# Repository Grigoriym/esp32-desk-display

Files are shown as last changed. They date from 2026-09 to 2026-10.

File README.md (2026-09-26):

# ESP32 Desk Display

A small always-on desk companion: an ESP32 drives a 0.96" OLED that shows
the time, the weather outside and inside, air quality and pollen, DWD
weather warnings, public holidays and the next U-Bahn departures. A rotary
knob switches between screens. Readings are also uploaded to a self-hosted
InfluxDB + Grafana dashboard, and a phone on the same WiFi can see them and
switch screens at `http://desk.local`.

Written in C on ESP-IDF, with a small hand-rolled SSD1306 driver and no
graphics library. All data sources are free and need no API key.

## Screens

Every screen has the time (`HH:MM`) flush left and the date (`DD/MM/YYYY`)
flush right on the top row. Turn the knob to go to the next or previous
screen (it wraps around). Press it to turn the panel off, and again to turn
it back on. Turning the knob while the panel is off also wakes it.

| Screen | Shows |
|---|---|
| **HOME** | DWD weather warning if one is out, otherwise the next public holiday; weather icon + outdoor temperature; indoor `IN 25C 43H`; rain hint (`RAIN 14:00`, `RAIN TILL 16:00`, `NO RAIN 12H`) |
| **OUTDOOR** | Sunrise/sunset, wind speed, today's max UV index |
| **AIR** | European AQI with its label, the two strongest pollen types and their levels |
| **INDOOR** | Temperature, humidity, pressure in hPa (BME280) |
| **BVG** | Next U-Bahn departures from one stop in one direction, with a `LEAVE IN N` / `GO NOW` / `HURRY` hint. One click counter-clockwise from HOME |

The font only has A-Z, 0-9, `:`, `-` and `/`, so `H` stands in for `%`.

At boot a status screen shows each subsystem coming up, with `--` changing
to `OK` or `NO`:

```
         HELLO

OLED    OK   PWR     OK
RTC     OK   BME     OK

WIFI    OK   NTP     OK
WEATHER OK
```

`PWR NO` means the last reset was a brownout (weak USB port or cable).

## Data sources

| Data | Source | Refresh |
|---|---|---|
| Time | NTP, kept through power loss by the DS3231 RTC (stores UTC) | RTC at boot, NTP after WiFi is up |
| Weather, sun, wind, UV, rain | [Open-Meteo](https://open-meteo.com/) forecast API | 15 min |
| Air quality, pollen | Open-Meteo air-quality API | 15 min |
| Weather warnings | DWD via [Bright Sky](https://brightsky.dev/) `/alerts` | 15 min |
| Public holidays | [Nager.Date](https://date.nager.at/) (Berlin + nationwide) | once a year |
| Departures | [`v6.bvg.transport.rest`](https://v6.bvg.transport.rest/) (community-run, has outages) | 60 s, only while the BVG screen is showing |
| Indoor | BME280 | 10 s |

A failed weather fetch is retried after 30 s, then at growing intervals up
to the normal 15 minutes.

## Resilience

- No RTC: the clock waits for NTP. No NTP: the RTC time is used.
- No WiFi within 15 s: boot shows `WIFI NO` and goes to the main screens on
  RTC time. WiFi keeps retrying in the background, and NTP and the weather
  follow once it connects.
- The BVG fetch and the dashboard upload run in their own tasks, so a slow
  or down server never freezes the clock or the knob.
- Summer/winter time switches automatically (POSIX TZ rule).

## Hardware

| Part | Notes |
|---|---|
| ESP32 DevKit (WROOM-32, 30-pin, 4 MB flash) | |
| 0.96" 128x64 I2C OLED, SSD1306/SSD1315 | I2C `0x3C` |
| DS3231 RTC module with coin cell | I2C `0x68`. Optional but recommended |
| BME280 | I2C `0x76`. Optional (indoor readings) |
| KY-040 rotary encoder | GPIO25/26/27. Optional (screen switching) |

All I2C modules share one bus (SDA GPIO21, SCL GPIO22), each wired
**directly to the ESP32, in parallel**, and powered from **3V3, never
5V**. Full pin table: [`docs/WIRING.md`](docs/WIRING.md).

## Build and flash

Requires [ESP-IDF](https://docs.espressif.com/projects/esp-idf/) (developed
on master, v6.x).

```sh
cp main/wifi_secrets.h.example    main/wifi_secrets.h     # SSID/password
cp main/bvg_secrets.h.example     main/bvg_secrets.h      # stop + direction IDs
cp main/metrics_secrets.h.example main/metrics_secrets.h  # dashboard host/token, empty = off
. ~/esp/esp-idf/export.sh
idf.py -p /dev/ttyUSB0 build flash monitor
```

The `*_secrets.h` files are gitignored, so credentials never get committed.
cJSON is pulled in automatically by the component manager.

## Dashboard

`server/` holds an InfluxDB 2 + Grafana setup in Docker Compose. The display
POSTs indoor, outdoor, air-quality and device values (heap, WiFi signal,
uptime) every minute. Run it on an always-on machine on the display's LAN:
see [`server/README.md`](server/README.md) and
[`server/INSTALL.md`](server/INSTALL.md).

## Phone access and API

The display serves a small page at **`http://desk.local`** (mDNS; the IP
from the boot log works too) with everything the screens show, refreshed
every 5 s, plus buttons for the screens and the panel. Home WiFi only, and
**no authentication**: anyone on the LAN can read it and switch screens.

| Request | Does |
|---|---|
| `GET /api/status` | JSON: `time`, `date` (`YYYY-MM-DD`), `screen`, `panel_on`, and `outdoor`, `indoor`, `air`, `warning`, `next_holiday`, `bvg`. A section is `null` until its first fetch or read succeeds (`--` on the panel); `warning` is `{"count": 0}` when there is none |
| `POST /api/screen?go=next\|prev\|home\|outdoor\|air\|indoor\|bvg` | Switch screens, like turning the knob. A screen by name also turns the panel on; `next`/`prev` while it's off only wake it, as the knob does |
| `POST /api/panel?set=on\|off\|toggle` | Panel on/off, like pressing the knob |

Commands answer `{"ok":true}` (`400` for a bad value) and apply within a
few hundred ms, or once a running fetch finishes. While `/api/status` is
being read (the last 2 minutes), departures are fetched even if the BVG
screen isn't up. The server also announces itself as `_http._tcp` for
discovery (Android NSD). Full contract (every field, discovery, errors,
polling): [`docs/API.md`](docs/API.md).

## Configuration

Settings are hardcoded constants. Change them and reflash:

| What | Where |
|---|---|
| Location (default: central Berlin) | `WEATHER_URL`, `AIR_URL`, `ALERTS_URL` in `main/weather.c` |
| Holiday region (default: `DE-BE`) | `HOLIDAYS_REGION` in `main/holidays.c` |
| Timezone (default: Berlin, automatic DST) | `LOCAL_TZ` in `main/clock.c` |
| Refresh intervals, WiFi timeout | `*_SECONDS` in `main/main.c` |
| BVG stop, direction, walking time | `main/bvg_secrets.h` |
| Display orientation | `0xA0`/`0xC0` in the init sequence in `main/display.c` (this build's panel is mounted upside-down; use `0xA1`/`0xC8` for the default orientation) |

## Development

Run these before pushing; CI (`.github/workflows/ci.yml`) runs the same on
every push:

| Script | Does |
|---|---|
| `tools/test.sh` | Host unit tests (Unity, ASan/UBSan) for the pure logic: parsers, screen layouts, font and icon bitmaps, time math, encoder decoding |
| `tools/format.sh` | clang-format (`--check` only reports) |
| `tools/lint.sh` | clang-tidy, checks in `.clang-tidy` |
| `tools/size_check.sh` | Fails if the app partition has under 15% free |
| `tools/serial_log.py [seconds] [regex]` | Resets the board and captures/greps the serial log |

clang-format and clang-tidy come from ESP-IDF's optional `esp-clang` tool.
New files are only checked once they're `git add`-ed.

## Project layout

```
main/
  main.c            boot sequence, status screen, main loop, knob handling
  screens.c         what each screen shows (pure, host-tested)
  display.c         SSD1306 driver; font.c: 5x7 font and icons
  clock.c           NTP sync, DS3231; clock_time.c: time math
  wifi.c            WiFi station
  http.c            shared HTTPS GET
  weather.c         weather, air quality and warnings fetch
  weather_parse.c   \
  air_parse.c        | JSON parsing (pure, host-tested)
  alerts_parse.c    /
  holidays.c        public holidays; holidays_parse.c
  bvg.c             departures, own task; bvg_parse.c
  bme280.c          indoor sensor driver
  encoder.c         KY-040 ISR + button task; encoder_decode.c
  metrics.c         dashboard upload, own task; metrics_format.c
  health.c          periodic heap/stack report in the log
  web.c             phone page + JSON API, mDNS; web_api.c (pure,
                    host-tested), page in web_index.html
test/               host unit tests + fixtures
tools/              test, format, lint, size and serial scripts
server/             InfluxDB + Grafana (Docker Compose)
docs/WIRING.md      pin table
```

Hardware bring-up tests (I2C scan, OLED pattern, BME280 chip ID, encoder)
live in a separate sibling project, `esp32-hw-checks`.

## License

[Apache License 2.0](LICENSE)

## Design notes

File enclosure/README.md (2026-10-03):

# Enclosure (ROADMAP task 15)

OpenSCAD model of the case, written from `MEASUREMENTS.md`. Open
`enclosure.scad` in OpenSCAD for the assembled view (modules shown as
coloured stand-in blocks). `-D cut=40` cuts the printed parts away left of
x = 40 to show the inside.

Part dimensions and how each part can be held: its Homebox entry
(`python3 ../../grappim-watcher/docs/esp32/inventory/parts.py show <part>`).
General modelling, clash-check and printability lessons:
`../../grappim-watcher/docs/esp32/ENCLOSURE_PLAYBOOK.md`. This file is this case only.

```
enclosure/export.sh   # clash check, then stl/enclosure/*.stl (gitignored) + renders/enclosure-*.png
```

The clash check fails if any printed part overlaps a module stand-in.

To look inside: **Window → Customizer**, untick `show_shell` (also
`show_base`, `show_hood`, `show_clamps`, `show_labels`), or set `cut`.
Stand-in colours: OLED steel blue, ESP32 black (antenna end orange),
carrier green, DS3231 navy, KY-040 red with a grey cap, sensors purple;
`show_labels` puts their names over them.

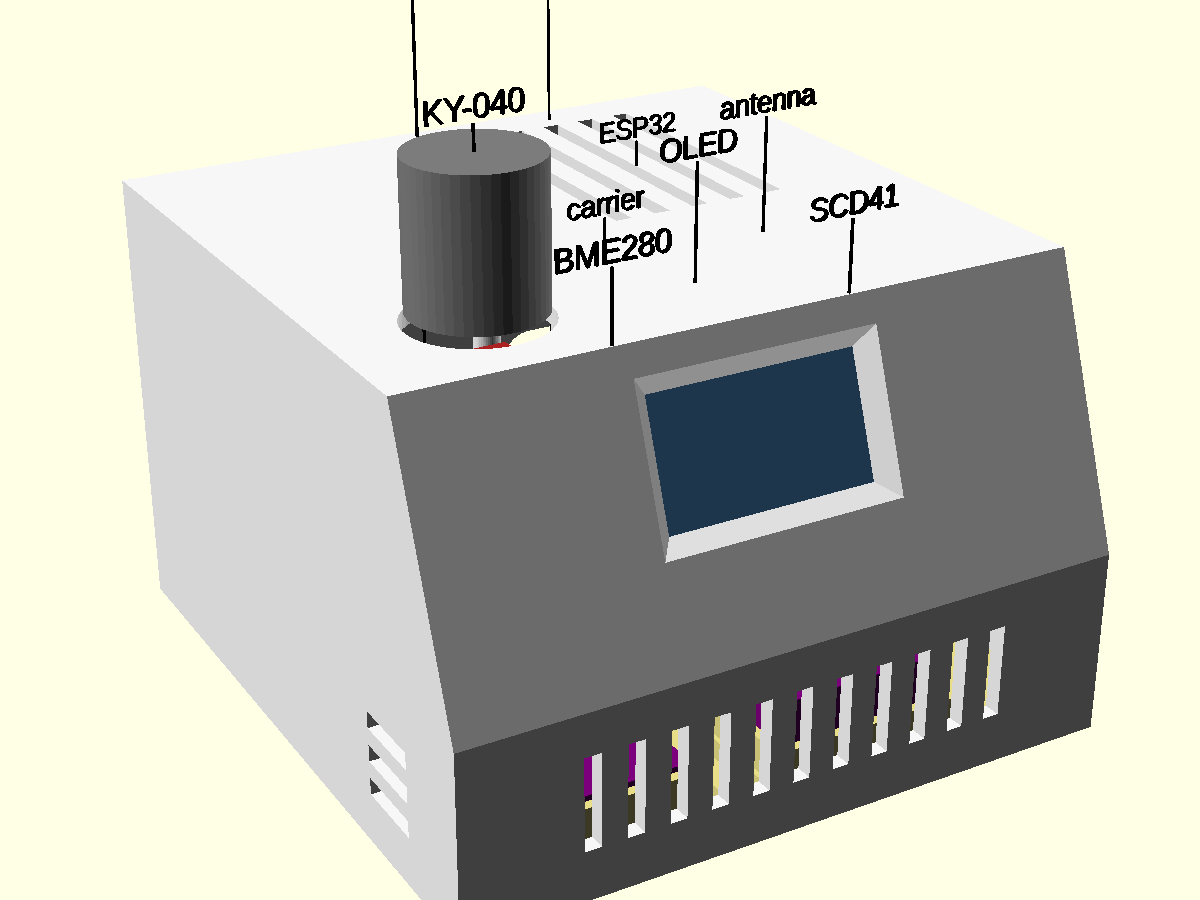
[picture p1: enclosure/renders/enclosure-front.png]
front
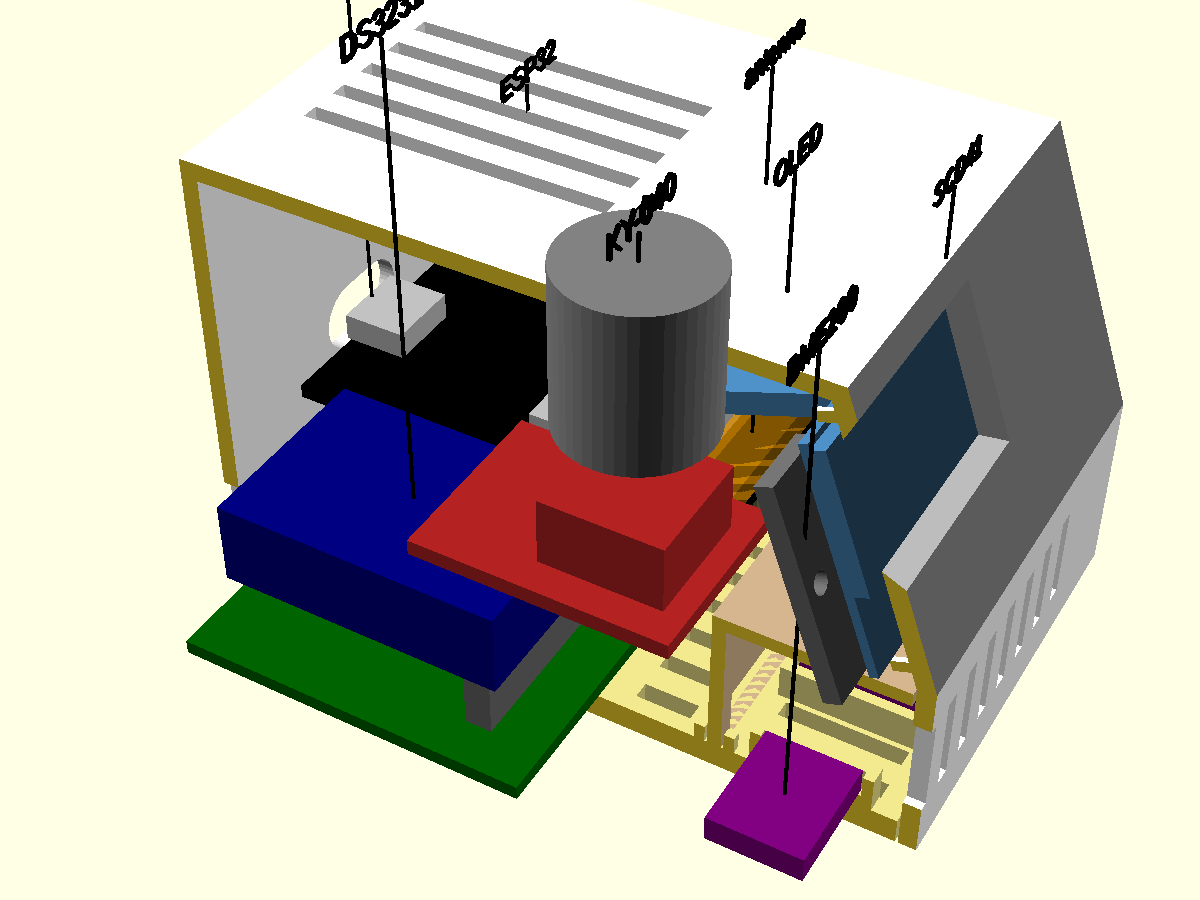
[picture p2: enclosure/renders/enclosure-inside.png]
inside
 

## v2: the carrier is the 4 x 6 cm board (`enclosure_v2.scad`)

The mock-up (2026-09-28) showed v1's carrier can't work: the 4 x 6 cm
perfboard has 14 holes across its 4 cm side, and an ESP32 pin row is 15, so
the ESP32 only fits along the 6 cm side. `enclosure.scad` (v1) is kept;
`enclosure_v2.scad` has two layouts, `carrier` in the Customizer:

| | `cut` | `whole` (**picked 2026-10-03**, the default) |
|---|---|---|
| board | turned front-to-back, cut to 40 x 44 (keep 17 hole rows) | uncut 60 x 40 |
| ESP32 | front-to-back | left-to-right |
| USB-C | out the back | out the right side |
| antenna | hangs off the board's front edge | over the board (and under the knob) |
| DS3231 | own holder on the floor, left, JST cable | own holder on the floor under the carrier (tall 16 mm standoffs), JST cable |
| case size | same 80 x 84 x 54 | same |

```
enclosure/export.sh enclosure_v2.scad carrier=cut        # or carrier=whole
enclosure/cardboard.py 2 enclosure_v2.scad carrier=cut   # -> cardboard-enclosure_v2-cut.pdf
```

**JST-XH sockets** are modelled on the board's hole grid (white, with the
mated plug + cable bend as a see-through gold block, labelled on top); the
clash check covers them against the ESP32, its headers, the DS3231 and the
case, and the model errors if one hangs off the board:

- `whole`: all five fit. BME280, SCD41, OLED along the front edge (row 0,
  under nothing; the plugs clear the ESP32's edge by only ~0.5 mm in plan),
  RTC and KNOB at the left end (col 0), next to the ESP32's antenna end.
- `cut`: only three fit (KNOB, OLED, SCD41, in the one free column left of
  the ESP32). **No room for BME280 and RTC**: the ESP32 covers the rest of
  the board, and a plug is too tall to go under it.

The hole grid is ASSUMED centred on the board. The DS3231's pins (both
ends) are modelled with the cable soldered on, not a Dupont plug.

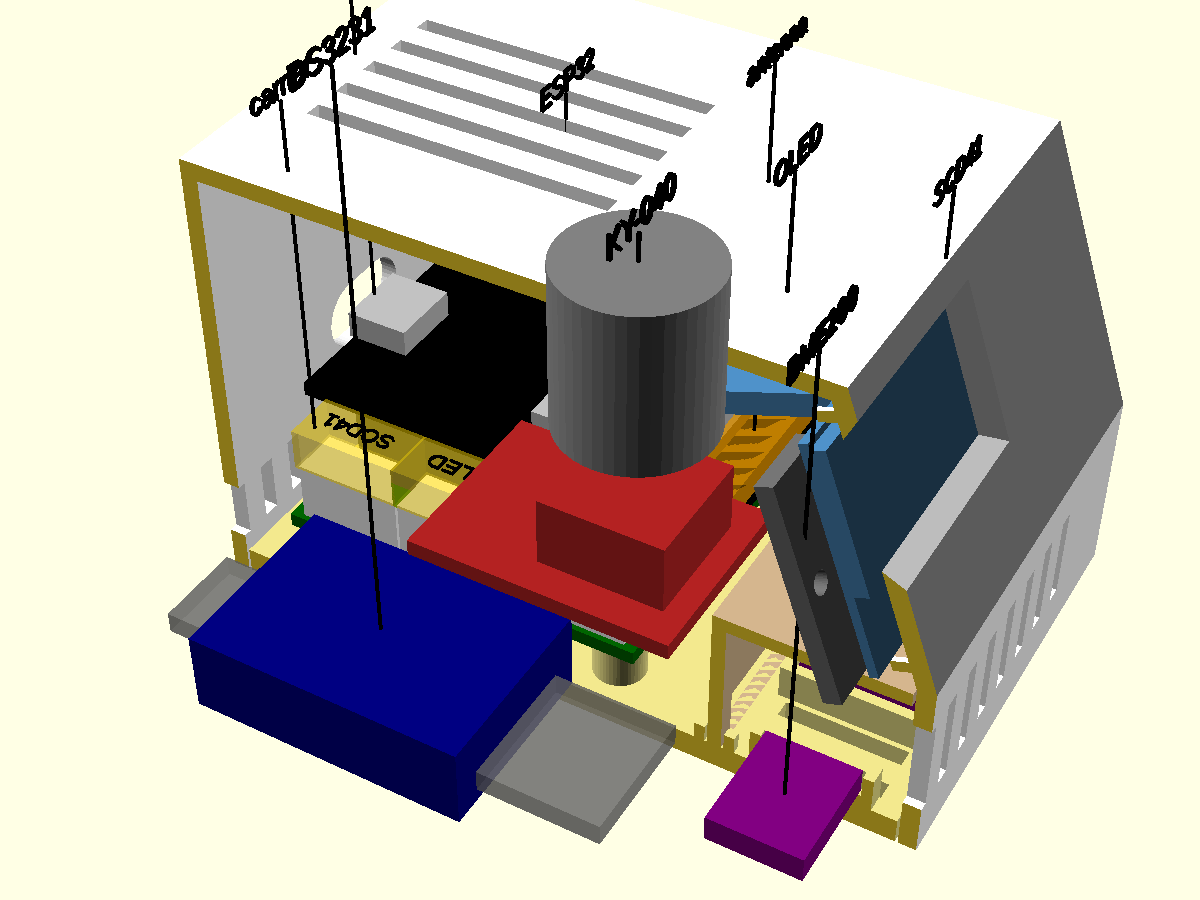
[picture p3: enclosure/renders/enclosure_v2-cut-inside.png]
cut
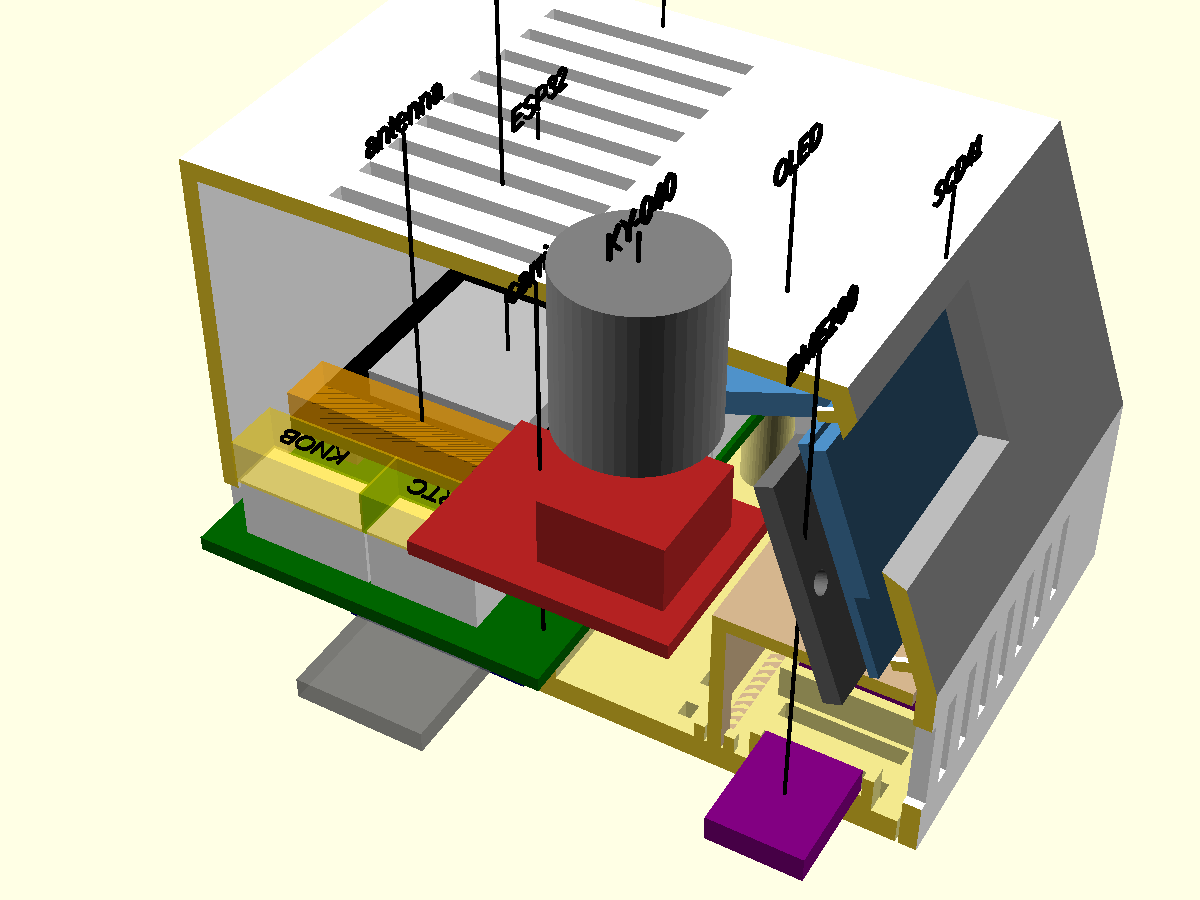
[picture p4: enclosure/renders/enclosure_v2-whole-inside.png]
whole
 

## v3: ESP32 mini instead of the DevKit (`enclosure_v3.scad`, 2026-10-03)

The current model. v2's `whole` layout (board uncut, USB-C out the right
side) with the ESP32 mini (D1 mini layout, 31.5 x 39 mm) in place of the
DevKit. The mini plugs into four 10-pin female headers (pad lines in rows
1, 2, 11, 12; pads in cols 10-19), its USB end hangs ~3 mm off the board's
right edge. All five JST-XH sockets stack at the board's left end (cols
0-4, rows 0/3/6/9/12, pin lines along X), ~5 mm from the mini's antenna
end. Case size unchanged. Why the mini: it fits the board either way round,
so all sockets fit with the USB out the side. Its regulator (marked
`73L33`) has no known rating: a full-load test follows the soldering.

```
enclosure/export.sh enclosure_v3.scad
```

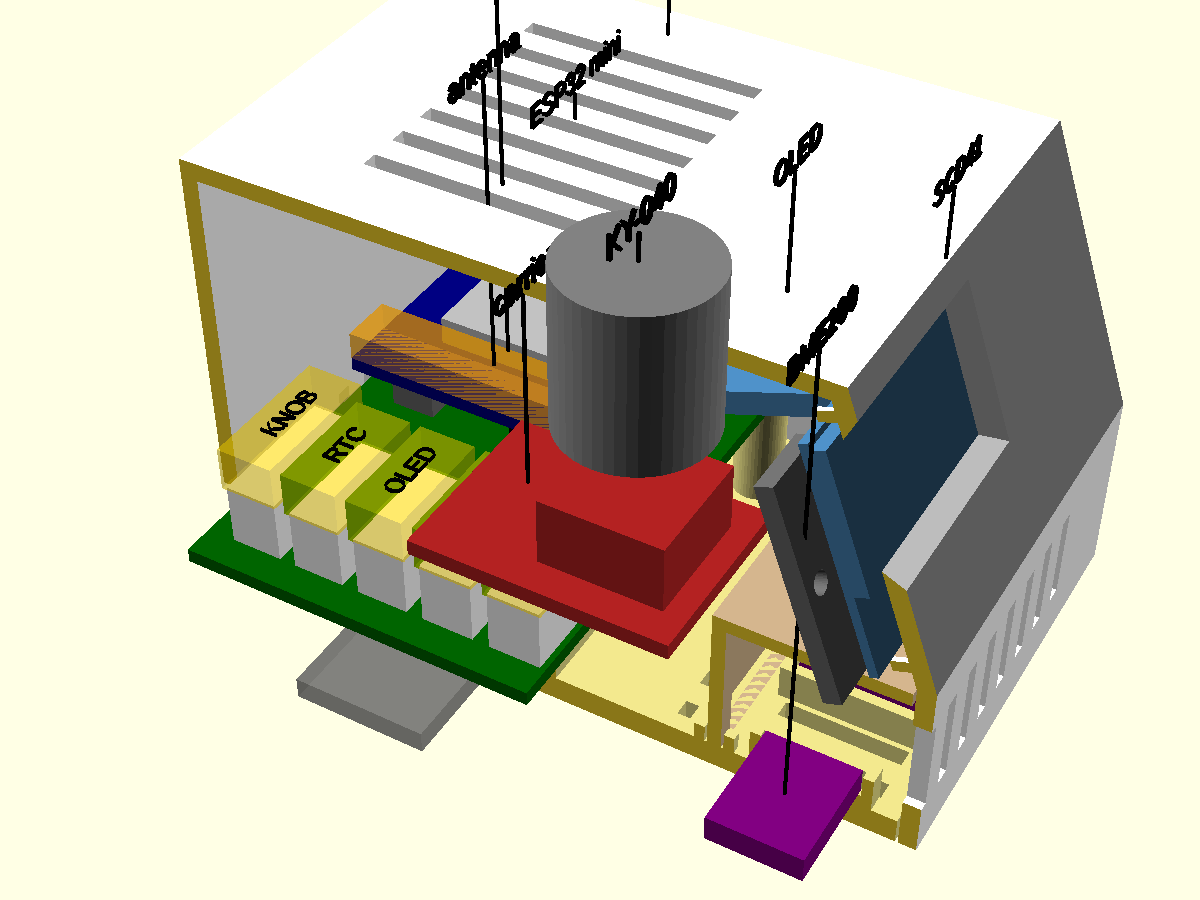
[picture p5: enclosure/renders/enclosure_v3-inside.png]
v3


## Cardboard mock-up

```
enclosure/cardboard.py [cardboard mm, default 2] [file.scad] [var=value]   # -> enclosure/cardboard*.pdf (gitignored)
```

Two A4 pages of 1:1 templates, sized from the model: 2 sides, front strip,
screen panel (with the window), top (with the knob hole), back (with the
USB hole), and a floor with the modules' outlines drawn on it (not holes) to lay the real ones on. Print at 100%
("Actual size") and check the 50 mm bar with a ruler. Panels other than the
sides are narrower by 2 × the cardboard thickness, so they fit between the
sides. The mock-up checks size, screen angle, knob reach, and cables and
battery space; not the printed fits or the heat.

## Layout

80 x 84 x 54 mm (W x D x H). A wedge: the OLED sits on a panel tilted 20°
back, with a vented strip under it and the knob on top (left).

- **Sensor bay** (BME280, SCD41): low at the front, walled off by the `hood`
  (a roof and back wall). Air comes in through the floor slots and leaves
  through the front and side slots. Nothing warm is inside it. Sensor cables
  go out through a notch in the hood's back wall. The bay is ~16 mm tall
  inside, so **solder the sensor cables straight on, or use right-angle
  pins**: a vertical header with a Dupont plug on it doesn't fit.
- **ESP32**: sits on the carrier board at the back right, with USB-C out the
  back. Its antenna end hangs off the carrier's front edge (no copper under
  it) and has nothing above it. Top slots over it let its warm air out;
  intake slots are low on the back and in the floor.
- **Carrier board**: 60 x 40 mm cut from a Miuzei perfboard, on 4 standoffs
  (5 mm). Place it on the printed base, mark the standoff holes through, and
  drill them to 2 mm. The ESP32 and DS3231 plug into 8.5 mm female headers.
- **OLED**: glass flat against the panel's inner face, located by 4 corner
  stops, held by two printed clamp bars. Each bar is screwed to a post
  beside the board and presses on the PCB's side edge. The board's own
  corner holes aren't used: the glass reaches almost to them, so there's no
  room for a screw post. Pins face up. If the picture comes out upside down,
  flip the two orientation bytes in `display.c`, not the board.
- **Knob**: the KY-040 board sits flat under the top, pins to the back. Push
  it up into two snap hooks on its long edges and it rests against 4 pads.
  The cap goes on from outside afterwards.
- **Base**: the floor plate goes into the open bottom of the shell. It's held
  by 4 × M3 screws from below into the shell's corner bosses, so the case
  opens without touching the wiring. There's room left for a battery later.

## Parts to print

| STL | Qty | Orientation (as exported) | Notes |
|---|---|---|---|
| `shell` | 1 | upside down, top on the bed | no supports expected; check the USB hole's 13 mm bridge |
| `base` | 1 | flat | |
| `hood` | 1 | roof on the bed | |
| `clamp` | 2 (file has both) | flat | |
| `test_front` | 1 | like the shell | **print this first**: screen panel + top front with the knob mount |

Material: PETG preferred (PLA softens ~55 °C, e.g. in direct sun). Fit
clearance in the model is 0.3 mm (`clr`): ask the person printing it.

## Hardware

- 4 × M3 × 8 self-tapping (base → shell)
- 2 × M2 × 5 self-tapping (OLED clamp bars)
- 4 × M2 × 6 self-tapping (carrier board → standoffs)
- 4 self-adhesive rubber feet, ≥ 2 mm tall (they lift the floor slots off the desk)
- JST-XH connectors and cables, see ROADMAP task 15

## Assumed, not measured

Marked `ASSUMED` in `enclosure.scad`; the test print shows whether they're
right: the OLED lit area's
position (±0.5 from a photo), the EC11 body size, the ESP32/KY-040 PCB
thickness (1.6), and the female header height (8.5).

## Test print checklist (`test_front`)

1. OLED: the glass sits flat between the 4 stops, and the lit area is
   centred in the window with no dark edge.
2. The clamp bars screw down without bending the board.
3. KY-040: it snaps in, the shaft is centred in the 16 mm hole, and the cap
   turns and presses without rubbing the top.

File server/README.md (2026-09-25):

# Dashboard server

InfluxDB (stores the readings) + Grafana (the dashboard page), in Docker
Compose. The display POSTs indoor, outdoor, air-quality and device values
every minute (`main/metrics.c`); Grafana shows them as graphs over any time
range.

Run it on an **always-on machine on the display's WiFi/LAN**: the ESP32
talks plain HTTP to it and can't reach Tailscale.

## Setup

Full step-by-step (prerequisites, verification, firewall, what to hand
back) for setting it up on another machine: **`INSTALL.md`**. Short
version:

1. Copy this `server/` folder to the machine, then in it:

   ```sh
   cp .env.example .env
   # INFLUX_TOKEN: openssl rand -hex 32; INFLUX_ADMIN_PASSWORD: anything
   docker compose up -d
   ```

2. Firmware: `cp main/metrics_secrets.h.example main/metrics_secrets.h`,
   set `METRICS_HOST` to the machine's LAN IP and `METRICS_TOKEN` to the
   same `INFLUX_TOKEN`, build and flash. The boot log says
   `metrics: uploading to <ip>`, then `metrics: upload OK` about a minute
   later (or `upload failed: ...`, logged once until it recovers).

3. Open `http://<machine>:34897`: the "Desk display" dashboard is the home
   page, no login needed (read-only). Log in as `admin` /
   `INFLUX_ADMIN_PASSWORD` to change things; the provisioned dashboard
   itself is read-only: edit `grafana/make_dashboard.py` and run it
   (`python3 grafana/make_dashboard.py` regenerates
   `grafana/dashboards/desk.json`; Grafana reloads it). Every panel has an
   (i) tooltip saying what its numbers mean; keep that when adding one.

Give the machine a fixed LAN IP (DHCP reservation in the router), or the
display loses it after a router restart.

## Data

Bucket `desk`, org `desk`, kept forever (a few KB a day). Measurements,
all fields floats, tag `device=desk`:

| Measurement | Fields |
|---|---|
| `indoor` | `temp_c`, `humidity`, `pressure_hpa` (BME280, 10 s old at most) |
| `outdoor` | `temp_c`, `wind_kmh`, `uv`, `weather_code` (Open-Meteo, refreshed every 15 min) |
| `air` | `aqi`, `alder`, `birch`, `grass`, `mugwort`, `ragweed` (same cadence) |
| `device` | `uptime_s`, `heap_free_kb`, `rssi` |

A measurement only appears once the display has data for it. Timestamps are
set by InfluxDB on arrival.

InfluxDB's own UI (`http://<machine>:34898`, `admin` / password) has a data
explorer for ad-hoc queries.

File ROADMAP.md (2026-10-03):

# Roadmap

One task per session. Tick it off (with the date) when it's done and verified
on the physical display, and note anything the next task needs to know.

- [x] **1. Automatic summer/winter time** (2026-09-23): POSIX TZ rule
  `CET-1CEST,M3.5.0,M10.5.0/3` in `main/clock.c` replaces the hand-flipped
  `UTC_OFFSET_HOURS`. RTC still stores UTC.
- [x] **2. Sunrise/sunset + wind/UV** (2026-09-23): same Open-Meteo request
  plus `daily=sunrise,sunset,uv_index_max&timezone=Europe/Berlin` (sun times
  arrive already local, DST included). `weather_fetch()` now fills a
  `weather_t`; `draw_weather()` in `main/main.c` draws rows 3, 6
  (`RISE 06:53` / `SET 19:02`) and 7 (`WIND 6KMH` / `UV 4`). UV is today's
  max, not current. Rows 6-7 are candidates to move to their own screen in
  task 3.
- [x] **3. KY-040 rotary encoder + multiple screens** (2026-09-24)
  - [x] Bring-up check in `../esp32-hw-checks` (2026-09-24): CLK D25, DT
    D26, SW D27 (see `docs/WIRING.md`), connected through a socket on the
    perfboard. ISR quadrature decode: **4 steps per detent** confirmed (full-step
    part), direction correct, no missed or reversed clicks on a fast spin
    (~30-40 ms per detent), button clean with 30 ms debounce, no double
    presses. The decode + debounce code there can be lifted into this firmware.
  - [x] Screen rotation (2026-09-24): `main/encoder.c` (ISR rotation + polled
    button -> event queue). Screens in `main/main.c` (`screen_t`,
    `draw_screen()`): HOME (icon+outdoor temp, `IN 25C 43H`), OUTDOOR
    (sunrise/sunset, wind/UV), INDOOR (temp, humidity, pressure). Clock row
    on page 0 of all of them. Turn = next/previous (wraps), press = HOME
    (press = panel off/on since 2026-09-25, verified on the panel).
    New screens (BVG, task 4): add a `screen_t` value and a `case`.
    Auto-return to HOME after idle and a screen-position indicator were
    considered and dropped (2026-09-25): not wanted.
- [x] **4. BVG departures screen** (2026-09-24; verified on the panel with
  real data during one of the wrapper's rare successful fetches: only U5
  towards Hbf, minutes match the times, nothing under 6 min). U Cottbusser Platz, U5 towards Hbf; stop
  and direction IDs in gitignored `main/bvg_secrets.h` (template:
  `bvg_secrets.h.example`). `main/bvg.c` fetches in a background task, only
  while the screen is showing, every 60s; the API's `direction=<next stop
  id>` filter picks the direction (U Kienberg = towards Hbf), which also
  catches short-turning trains. Screen 4 (one click CCW from HOME): title
  `U5 HAUPTBAHNHOF`, `LEAVE IN N` (12+ min left), `GO NOW` (11), `HURRY` (6-10), then
  up to 3 trains >= 6 min away as `HH:MM   N MIN`. Verified: no crash, and a
  down API no longer freezes clock/encoder.
- [ ] **4b. Switch BVG to the official VBB API** — *blocked on the key*.
  Why: the community wrapper
  `v6.bvg.transport.rest` returns 503 on every data request and has done so
  mostly since July ([bvg-rest#30](https://github.com/derhuerst/bvg-rest/issues/30),
  no maintainer reply), while BVG's own backend (`bvg.hafas.cloud`, what the
  wrapper relays) answered fine when queried directly, so the wrapper is
  what's broken. Decision: switch to the **official VBB API**. Access
  requested by email to api@vbb.de on 2026-09-24 (test system first, then
  production after accepting their terms). When the key arrives: key into
  `bvg_secrets.h`, new parser in `bvg.c` (different response format;
  screen and background task stay). Talking to `bvg.hafas.cloud` directly
  was considered and not chosen: unofficial web-app backend with a token
  copied from BVG's web app. Self-hosting the wrapper (Docker image
  `derhuerst/bvg-rest:6`, last updated Oct 2025, untested) was also
  considered as a bridge and not chosen: same unofficial backend, and the
  ESP32 can't join Tailscale, so it would need a host on the display's
  own LAN or a public HTTPS one. It would need only a URL change in
  `bvg.c` (same response format) if revisited.
- [x] **4c. Code quality: lint, tests, CI** (2026-09-25) (Android analogues: ktlint,
  detekt/lint, unit tests, GitHub Actions)
  - [x] clang-format (2026-09-25): `.clang-format` + `tools/format.sh
    [--check]`, whole codebase reformatted in one commit.
  - [x] Host unit tests (2026-09-25): `tools/test.sh`, Unity + gcc with
    ASan/UBSan. JSON parsing split into `weather_parse.c` / `bvg_parse.c`;
    12 tests (parsers, weather code -> icon, stop-name cleanup).
  - [x] More host tests (2026-09-25): pure logic split out again, like
    the parsers: `clock_time.c` (`utc_to_epoch()` vs glibc `timegm()` for
    every day 2000-2100, BCD, the Berlin DST switch moments through
    `LOCAL_TZ`), `encoder_decode.c` (quadrature decode + button debounce,
    fed by the ISR / button task), `font.c` (glyph tables + `font_blit()`).
    Glyphs and weather icons are checked as ASCII art (`test/art.h`): a
    wrong bit prints the picture as drawn next to the expected one. 47
    tests. Real BVG capture added as `bvg_real.json` (2026-09-25).
  - [x] clang-tidy (2026-09-25): `.clang-tidy` + `tools/lint.sh`, clean.
    Tidied on the way (none were live bugs): int->time_t widening in `utc_to_epoch()` made
    explicit, int->float conversions in `bme280.c` made explicit, missing
    `default:` in the umlaut switch.
  - [x] Split `app_main()` and `draw_screen()` (2026-09-25): screen text in
    `screens.c` (pure, 8 host tests incl. the LEAVE IN / GO NOW / HURRY
    boundaries and the midnight wrap); `app_main()` is now boot steps +
    one `tick_*()` per periodic job. Complexity NOLINTs gone.
  - [x] GitHub Actions (2026-09-25): `.github/workflows/ci.yml`, firmware
    build + format check + host tests + clang-tidy.
- [x] **5. Later, from the Freenove kit** (2026-09-25)
  - PIR motion sensor and passive buzzer: dropped (2026-09-25), not wanted
    (display runs ~1 h/day, so no burn-in concern; no sounds).
  - [x] Photoresistor (2026-09-25): LDR + 10k divider soldered on D34
    (`docs/WIRING.md`), reads fine (`esp32-hw-checks` LDR check). **Auto-dim
    dropped**: this SSD1315 can't visibly dim. Tried with a knob-driven
    trial: contrast 0x01-0x40 look identical, 0x00 switches the panel off
    (also with shorter pre-charge / lower VCOMH), 0xFF only slightly
    brighter. The dimming firmware (ADC reader, hysteresis logic) was
    written and removed unmerged. **LDR removed from the board**
    (2026-09-25): no use for it without dimming.

- [x] **6. Rain hint on HOME** (2026-09-25, `NO RAIN 12H` seen on the
  panel): page 7 shows `NO RAIN 12H`, `RAIN 16:00` (next rainy hour),
  `RAIN TILL 15:00` (raining now) or `RAIN NEXT 12H`. Same Open-Meteo
  request plus `hourly=precipitation_probability&forecast_hours=12`
  (hourly starts at the current hour, local time); an hour counts as rainy
  at >= 50% (`WEATHER_RAIN_MIN_PROB`), null = dry. Parsing in
  `weather_parse.c`, text in `screens.c`, both host-tested. Response is
  ~1.2 KB of the 2 KB buffer in `weather.c`.

- [x] **7. Air quality + pollen screen** (2026-09-25, `AQI 23 FAIR` /
  `POLLEN NONE` seen on the panel): screen AIR, between OUTDOOR and INDOOR (two clicks CW from
  HOME). `AQI 23` / `FAIR` (European AQI bands: GOOD <=20, FAIR <=40,
  MODERATE <=60, POOR <=80, VERY POOR <=100, EXTREME), then the two
  strongest of alder/birch/grass/mugwort/ragweed as `BIRCH` / `HIGH`, or
  `POLLEN NONE`. Pollen scale is one rough scale for all types (grains/m3:
  1-10 LOW, 11-50 MED, >50 HIGH). Current values from Open-Meteo's
  air-quality API, fetched with the weather; an air failure makes the
  fetch retry with the weather backoff. Pollen is 0 off season (Sep-Jan),
  so the pollen rows only get real data from spring.

- [x] **8. Dashboard** (2026-09-25): the display POSTs its readings every
  minute to InfluxDB, Grafana shows them (`server/`, Docker Compose, setup
  in `server/README.md` / `server/INSTALL.md`). First tested with the stack
  on the dev machine; since 2026-09-25 it runs on the always-on home box,
  Grafana at `http://192.168.0.139:34897/`, firmware reflashed with its IP
  and token (`upload OK` in the boot log), dev-machine stack and volumes
  removed.

- [x] **9. DWD weather warnings on HOME** (2026-09-25; the fetch runs on
  the device, `alerts fetched (none)`, but Berlin had no warning to see on
  the panel yet): Bright Sky
  `https://api.brightsky.dev/alerts?lat=52.52&lon=13.405&tz=Europe%2FBerlin`
  (free, no key; warn cell 711000101 "Berl. - Mitte"), fetched after the
  air quality every 15 min. While a warning is out, HOME shows it on
  page 1, under the clock (the rain hint stays on page 7): DWD's English label uppercased (`HEAVY RAIN`),
  or for one that hasn't started yet the label plus its start, `18:00` today
  or `26/09` later. Pick: started beats upcoming, then severity
  (minor/moderate/severe/extreme = DWD yellow/orange/red/violet). Test
  messages and all-clears are skipped. Heap low point 139 KB after it
  (was 145). Still open: see a real warning on the panel, and replace the
  hand-written fixture with a capture of it.

- [x] **10. Berlin public holidays** (2026-09-25; `NEXT HOLIDAY 03/10` seen
  on the panel; the fetch runs on the
  device, `holidays 2026 fetched (10 in Berlin, next 20261003 GERMAN UNITY
  DAY)`): Nager.Date `https://date.nager.at/api/v3/PublicHolidays/<year>/DE`
  (free, no key), keeping `global: true` or `DE-BE` in `counties`. Fetched
  at the first chance after boot (clock set + WiFi), then only when the
  next year's list is needed (after 26 Dec); a failure retries in 30 min.
  HOME page 1 (under the clock) shows `NEXT HOLIDAY` + `DD/MM`, or the
  holiday's English name on the day (`GERMAN UNITY DAY`, `.`/`'` dropped:
  `ST STEPHENS DAY`); a DWD warning takes that row. Each holiday is one day
  in the API, so back-to-back ones (25/26 Dec) just change the line.
  School holidays (multi-day) are a different source, not covered. Needed
  `CONFIG_MBEDTLS_CERTIFICATE_BUNDLE_CROSS_SIGNED_VERIFY` (see CLAUDE.md).

- [x] **11. Web page + JSON API on the display** (2026-09-26; API checked
  from the PC over `desk.local`, phone page and panel switching confirmed
  by the user; see README "Phone access and API") (phone access, home WiFi
  only): `esp_http_server` + mDNS so it answers at `http://desk.local`.
  `GET /api/status` = the current `screen_data_t` as JSON (time, outdoor/
  indoor, AQI/pollen, BVG, warning/holiday); `POST /api/panel` (off/on) and
  `/api/screen` (next/prev/by name), same effect as the knob, handed to the
  main loop through the encoder event queue rather than touching the display
  from the server task. A tiny HTML page at `/` for any phone browser. JSON
  building pure + host-tested (like `metrics_format.c`); the server task
  goes in `TASKS[]` in `health.c`. Budget: ~30-50 KB flash (35% free), check
  heap after. No auth (LAN only), note it in the README.
  Done as planned, plus: web commands reuse the encoder queue with a new
  `input_event_t` (`main/input.h`); reading `/api/status` keeps BVG fetching
  for 2 min (else `bvg` would be stale off-screen). Cost: +74 KB flash (30%
  free, was 35%; mDNS is most of it), heap lowest 116 KB (was 139), stack
  left httpd 2.4 KB / mdns 2.2 KB. A command sent during a boot fetch waits
  until the fetch ends (seen: ~10 s).

- [ ] **12. Android app** (Kotlin/Compose, separate repo, built by a
  separate agent from the user's app template; everything it needs about
  the device is in `docs/API.md` + `docs/api/status.example.json`): finds
  the display via NSD (`_http._tcp`, mDNS name from 11), reads
  `/api/status`, one card per screen + panel/screen buttons, and a Glance
  home-screen widget (outdoor/indoor temp, next departure).
  Repo: `../deskmate` ([github.com/Grigoriym/Deskmate](https://github.com/Grigoriym/Deskmate)),
  started 2026-09-26; its progress is the `docs/CHECKLIST.md` banner there.

WiFi connect timeout: done 2026-09-25, see Open questions in `CLAUDE.md`.

- [x] **13. CO2 sensor: SCD41** (done 2026-09-26) (on hand, model confirmed by the user
  2026-09-26). Step by step, as
  with the other modules: power budget first, then a bring-up check in
  `../esp32-hw-checks`, then solder its own socket, then the firmware.
  SCD41: I2C at **0x62** (no clash, add to
  `KNOWN_I2C`), 2.4-5.5 V so power it from 3V3; averages ~15 mA in periodic
  mode but its datasheet peak is ~175-205 mA in short pulses, which on top
  of the WiFi TX peak goes past the ~450 mA guardrail in CLAUDE.md: add
  its row to the power table and watch for `PWR NO` / brownout (low-power
  periodic mode, 30 s interval, cuts the average to ~3 mA). First reading
  ~5 s after start, then every 5 s. Then: its value on the
  INDOOR screen (a free row), in the metrics upload and in `/api/status`
  (update `docs/API.md` + `docs/api/status.example.json`).
  Progress: power row + `0x62` in `KNOWN_I2C` done; breadboard check in
  `esp32-hw-checks` passed 2026-09-26 (serial C2B4A5073B77, CRC OK, CO2
  813 ppm, 1506 after breathing on it). No extra cap: the module has its own;
  a tested 47 µF / 25 V is on hand if `PWR NO` ever shows. Soldered on the board 2026-09-26, boot scan
  shows `0x62: SCD41 CO2`, reset reason power-on (no brownout). Firmware reads it and shows `CO2 <ppm>`
  on INDOOR (first readings 1037 / 863 ppm, 2026-09-26). Metrics upload: `co2,device=desk ppm=<n>`
  line, arriving in InfluxDB (899 ppm, 2026-09-26); Grafana CO2 tile + graph
  (row under the tiles). `/api/status` has `"co2": {"ppm": <n>}` (own
  section, `null` without the sensor; `docs/API.md` + example updated), the
  phone page shows it in the Indoor card (622 ppm live, 2026-09-26).

- [x] **14. SCD41 self-calibration (ASC): check and decide** (2026-09-26):
  boot log now reads the settings while the sensor is idle:
  `ASC enabled 1, target 400 ppm, initial period 44 h, standard period
  156 h` (factory defaults; commands checked against the SCD4x datasheet
  v1.7). Datasheet: ASC counts only unbroken stretches of >= 4 h of
  measuring (low-power periodic included) and wants >3 min of ~400 ppm air
  per period. **Decision: keep ASC on**, nothing written to the sensor: the
  display runs overnight (stretches count) and the window is usually open
  at the desk. No API change. Fallback if readings drift low (winter): ASC
  off + one-off FRC outdoors, see the SCD41 row in CLAUDE.md. An "air the
  room" hint on screen was considered and not built: not needed while
  the window is open anyway.

- [ ] **15. Enclosure + soldered carrier board** (planned 2026-09-26;
  **the current main task**).
  Everything is on a solderless breadboard now (a first all-soldered
  perfboard attempt was abandoned). The case comes first, the board is
  designed to fit it. No 3D printer here: the case is an OpenSCAD model in
  `enclosure/`, exported to STL and printed by someone who has a printer
  (ask them about PLA vs PETG and their clearance, ~0.2-0.3 mm).
  - **Heat is the main constraint**: ESP32 + regulator give off ~0.5-0.8 W,
    enough to make the BME280 read 3-5 °C high in a closed box. Sensors
    (BME280, SCD41) go in a walled-off, vented bay, low and at the front; the
    ESP32 high and at the back with top vents, so its warm air rises away.
    Keep the ESP32's PCB antenna end clear of wires/boards.
  - Rough form: small wedge, OLED window (visible area ~22x11 mm, not the
    full 27 mm board) on the tilted front, knob under it or on top, USB-C
    out the back.
  - Carrier board (Miuzei perfboard): ESP32 in two 15-pin female headers,
    DS3231 on the board, **JST-XH 2.54 mm** keyed connectors out to the
    OLED, BME280, SCD41 (4-pin) and KY-040 (5-pin). All I2C connectors in one
    pin order, **GND, 3V3, SDA, SCL**; the cables do the per-module swap.
    I2C cables < ~20 cm. Board outline and holes match the case's posts.
    A KiCad/JLCPCB version only if the perfboard one proves the layout.
  - **Next session starts here**: the cardboard mock-up (2026-09-28)
    showed the 4 x 6 cm carrier can't hold the ESP32 across its 4 cm side
    (14 holes, the ESP32 needs 15). `enclosure/enclosure_v2.scad` has two
    fixes (`carrier=cut`: board cut to 40 x 44, USB out the back;
    `carrier=whole`: board uncut, USB out the right side); the DS3231 gets
    its own cable in both. Sockets modelled on the hole grid: only `whole`
    fits all five JST-XH sockets (`cut` fits 3), so `whole` is the
    recommendation; **the user picked `whole` on 2026-10-03** (USB out
    the right side; now the default). **Then the ESP32 mini replaces the
    DevKit** (2026-10-03, `enclosure/enclosure_v3.scad`: same layout, all
    five sockets in one stack at the board's left end; a bare mini ran the
    firmware with no brownout, full-load test after soldering). Wiring explained visually
    in the "Carrier Board Wiring" artifact (see memory). Open before the
    soldering plan: measure where the real board's hole grid sits (model
    assumes centred), check the ~0.5 mm plug-to-ESP32 clearance of the
    front sockets. Then test print of `test_front`, see `enclosure/README.md`.
  - Steps: [x] measure every part (`enclosure/MEASUREMENTS.md`, 2026-09-28)
    -> [x] OpenSCAD model + preview renders (`enclosure/`, see its README;
    2026-09-28: 80 x 84 x 54 mm, knob on top, OLED held by clamp bars, the
    carrier is 60 x 40 mm) -> [x] KY-040 shaft position (~8.6 mm from
    the end away from the pins, not the middle) -> [ ] test
    print of the front panel only (`test_front` STL: OLED window, knob mount) -> [ ] full print
    -> [ ] perfboard layout on a grid, solder -> [ ] assemble, then compare
    BME280 with a reference thermometer with the case open vs closed.

Other open items (not scheduled): battery backup — see Open questions in
`CLAUDE.md`.

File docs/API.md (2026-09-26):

# Desk display HTTP API

The contract between the desk display (this repo's ESP32 firmware) and
clients such as the phone app. Everything a client needs to find the
display, read its data and control it is here. The Android side is out of
scope.

- Example response: [`docs/api/status.example.json`](api/status.example.json).
  A host test (`test_matches_documented_example` in `test/test_web_api.c`)
  checks that the firmware produces exactly that file for the matching data,
  so the file and the firmware can't drift apart. Use it as the client's
  parsing fixture.
- Firmware side: `main/web.c` (server, mDNS), `main/web_api.c` (JSON,
  command parsing).

## Network

- **Home WiFi (LAN) only.** The ESP32 isn't reachable from outside the
  home network (no Tailscale on it, no port forwarding).
- **Plain HTTP on port 80**, no TLS. Android blocks cleartext HTTP by
  default, so the app has to allow cleartext traffic (for local/LAN hosts
  at least).
- **No authentication.** Anyone on the LAN can read and control it.
- The display gets its IP by DHCP (currently `192.168.0.147`, but it can
  change), so a client should find it by discovery rather than a fixed IP.

## Finding the display

Two ways, both provided by the firmware's mDNS responder:

| Method | Value |
|---|---|
| **DNS-SD / NSD service discovery** (preferred on Android: `NsdManager`) | service type `_http._tcp.`, service name **`Desk display`**, port **80**, no TXT records |
| **mDNS hostname** | `desk.local` → `http://desk.local/` |

Not every Android version resolves `.local` hostnames through the normal
DNS path, so use NSD discovery (then resolve the service to get host +
port) and keep a manual IP entry as a fallback. Filter discovered
`_http._tcp.` services by the service name `Desk display`: other devices
(printers, routers) announce `_http._tcp.` too.

## Endpoints

| Method + path | Purpose |
|---|---|
| `GET /api/status` | Everything the display shows, as JSON |
| `POST /api/screen?go=<value>` | Switch the screen shown on the panel |
| `POST /api/panel?set=<value>` | Turn the panel (OLED) on or off |
| `GET /` | The display's own small web page (not needed by the app) |

Parameters go in the **query string**; POST bodies are ignored and can be
empty.

### `GET /api/status`

`200`, `Content-Type: application/json`, `Cache-Control: no-store`, about
1 KB. Full example in [`api/status.example.json`](api/status.example.json).

Top level:

| Field | Type | Meaning |
|---|---|---|
| `time` | string `"HH:MM"` | Display's local time (Europe/Berlin, DST handled), when the response was built |
| `date` | string `"YYYY-MM-DD"` | Display's local date. Right after a cold boot without network/RTC it can be 1970 until the clock syncs |
| `screen` | string | Screen currently on the panel: `home`, `outdoor`, `air`, `indoor`, `bvg` |
| `panel_on` | bool | Whether the OLED is on (off = dark, the display still runs and fetches) |
| `outdoor` | object or `null` | Weather outside, see below |
| `indoor` | object or `null` | Room sensor (BME280), see below |
| `co2` | object or `null` | Room CO2 (SCD41, a separate sensor), see below |
| `air` | object or `null` | Air quality and pollen, see below |
| `warning` | object or `null` | DWD weather warnings, see below |
| `next_holiday` | object or `null` | Next Berlin public holiday, see below |
| `bvg` | object or `null` | Next U-Bahn departures, see below |

**`null` means "no data yet"**: the first fetch or sensor read hasn't
succeeded since boot (the panel shows `--` then). Once a section has data
it stays, and a later failed fetch keeps the last good values. Exception:
`warning`, which goes back to `null` when a fetch fails (a stale warning
is worse than none). Clients should render every section independently and
handle `null` for each.

There are **no timestamps per section**; how old the data can be follows
from the refresh cadence:

| Section | Source | Refreshed |
|---|---|---|
| `outdoor`, `air`, `warning` | Open-Meteo, Open-Meteo air quality, DWD via Bright Sky | every 15 min (sooner retries after a failure) |
| `indoor` | BME280 on the device | every 10 s |
| `co2` | SCD41 on the device | every 30 s (`null` for the first ~30 s after boot) |
| `bvg` | BVG departures (community API, **often down**, see below) | every 60 s, but only while fetching is active (see `bvg`) |
| `next_holiday` | Nager.Date | once a year |

#### `outdoor`

| Field | Type | Meaning |
|---|---|---|
| `temp_c` | int | Current outdoor temperature, °C, rounded. A model value for central Berlin (Open-Meteo), not a station measurement: can read ~1-2 °C off on sunny mornings |
| `weather_code` | int | WMO weather code (Open-Meteo `weathercode`). The panel groups it as: 0-1 sun; 2, 3, 45, 48 cloud; 51-57, 61-67, 80-82 rain; 71-77, 85-86 snow; 95-99 storm; anything else cloud |
| `wind_kmh` | int | Current wind speed, km/h, rounded |
| `uv_max` | int | Today's maximum UV index, rounded |
| `sunrise`, `sunset` | string `"HH:MM"` | Today's, local time |
| `rain.in_h` | int | Hours until the first hour with ≥ 50% chance of rain, within the next 12 h: `0` = raining now (this hour), `-1` = no rain in the 12 h window |
| `rain.from` | string `"HH:MM"` or `""` | Start of that rainy hour; `""` when `in_h` is `-1` |
| `rain.until` | string `"HH:MM"` or `""` | First dry hour after it; `""` if it rains to the end of the window (or no rain) |

The panel shows `rain` as `NO RAIN 12H` (`in_h` -1), `RAIN <from>` (`in_h`
> 0), `RAIN TILL <until>` (`in_h` 0 with `until`), `RAIN NEXT 12H`
(`in_h` 0 without `until`).

#### `indoor`

| Field | Type | Meaning |
|---|---|---|
| `temp_c` | number, 1 decimal | Room temperature, °C |
| `humidity_pct` | number, 1 decimal | Relative humidity, % (40-60 is comfortable indoors) |
| `pressure_hpa` | number, 1 decimal | Air pressure at the sensor, hPa (not sea-level corrected) |

#### `co2`

| Field | Type | Meaning |
|---|---|---|
| `ppm` | int | CO2 in the room, ppm. Outdoor air is ~420. Below 800 fresh; 800-1000 fine; 1000-1400 stuffy, time to air the room; above 1400 open a window now |

`null` also when the display has no SCD41 fitted. (The sensor measures
temperature and humidity too, but reads a few °C high from self-heating,
so those aren't exposed: use `indoor`.)

#### `air`

| Field | Type | Meaning |
|---|---|---|
| `aqi` | int | European Air Quality Index (0 and up, lower is better) |
| `aqi_label` | string | Band of `aqi`: `GOOD` (≤ 20), `FAIR` (≤ 40), `MODERATE` (≤ 60), `POOR` (≤ 80), `VERY POOR` (≤ 100), `EXTREME` (> 100) |
| `pollen.alder`, `.birch`, `.grass`, `.mugwort`, `.ragweed` | int | Pollen in grains/m³, rounded. `0` = none or off season. The panel's rough scale: < 1 none, 1-10 low, 11-50 medium, > 50 high |

All five pollen keys are always present.

#### `warning`

`null` when unknown (no successful fetch, or the last one failed). Otherwise:

| Field | Type | Meaning |
|---|---|---|
| `count` | int | Warnings for Berlin in effect or announced; `0` = none. The other fields are **only present when `count` > 0** |
| `event` | string | The one warning worth showing, DWD's English label uppercased, e.g. `HEAVY RAIN`. Picked as: started beats upcoming, then more severe, then first listed |
| `severity` | string | `minor`, `moderate`, `severe`, `extreme` (DWD map colours yellow, orange, red, violet) |
| `started` | bool | Whether it is already in effect |
| `onset` | string | When it starts/started: local `"HH:MM"` if today, else `"DD/MM"` |

#### `next_holiday`

`null` until the holiday list is fetched, or when none is left this year
(the next year's list is fetched after 26 Dec).

| Field | Type | Meaning |
|---|---|---|
| `date` | string `"YYYY-MM-DD"` | Next Berlin public holiday, today included (it's today when `date` equals the top-level `date`) |
| `name` | string | English name, uppercased, letters/digits/spaces only: `GERMAN UNITY DAY`, `ST STEPHENS DAY` |

#### `bvg`

`null` until the first successful departures fetch. The source (the
community API `v6.bvg.transport.rest`) has long outages (503s), so **expect
`null` for long stretches**; a switch to the official VBB API is planned,
with the same fields here.

Departures are only fetched while the BVG screen is on the panel **or
`/api/status` was read in the last 2 minutes**. So a client polling the
status keeps them fresh; when nobody polls and the screen isn't up, the
list can be old (entries already gone are dropped, see `in_min`).

| Field | Type | Meaning |
|---|---|---|
| `walk_min` | int | Minutes it takes to walk to the stop: departures with `in_min` < `walk_min` can't be caught (the panel hides them) |
| `walk_comfort` | int | Minutes for a relaxed walk. The panel's hint for the first catchable train: `LEAVE IN <in_min - walk_comfort>` while positive, `GO NOW` at 0, `HURRY` below |
| `departures` | array | Up to 6, soonest first, one fixed stop and direction (configured on the device). Only departures still ahead (`in_min` ≥ 0); cancelled ones are already left out. Can be empty (nothing in the next hour) |
| `departures[].line` | string | e.g. `U5` |
| `departures[].direction` | string | Destination, uppercased ASCII (umlauts spelled out), e.g. `HAUPTBAHNHOF` |
| `departures[].time` | string `"HH:MM"` | Real departure time (delay included), local |
| `departures[].in_min` | int | Minutes from the response's `time` until then |

### `POST /api/screen?go=<value>`

| `go` | Effect |
|---|---|
| `next`, `prev` | Next / previous screen, wrapping (order: home, outdoor, air, indoor, bvg), like turning the knob. If the panel is off it only wakes it, without switching (same as the knob) |
| `home`, `outdoor`, `air`, `indoor`, `bvg` | Show that screen; also turns the panel on |

### `POST /api/panel?set=<value>`

| `set` | Effect |
|---|---|
| `on`, `off` | Panel on / off |
| `toggle` | Flip it, like pressing the knob |

### Command responses and timing

- Success: `200`, `application/json`, body `{"ok":true}`. The command is
  queued at that point, not yet applied.
- It's applied within a few hundred ms (measured: done 300 ms later). But
  while the device runs a network fetch in its main loop (at boot, and
  every 15 min for a few seconds) it waits until that ends; seen up to
  ~10 s right after boot.
- To show the new state, re-read `/api/status` shortly after (the
  display's own page waits 150 ms, then polls every 5 s). `screen` /
  `panel_on` change once it's applied.

### Errors

| Status | When | Body |
|---|---|---|
| `400` | Missing or unknown `go` / `set` value (values are lowercase, exact) | `text/html`, a short message |
| `404` | Unknown path | `text/html` |
| `405` | Wrong method (e.g. `GET /api/panel`) | `text/html` |
| `500` | Status JSON couldn't be built, or the command queue is full | `text/html` |

Network-level failures are normal too: the display reboots after a
firmware flash or a power blip (unreachable for ~15 s), and it's gone when
unplugged. Treat a timeout or refused connection as "display offline" and
keep showing the last data, marked stale.

## Client guidelines

- **Polling**: every 5 s while visible is fine (that's what the display's
  own page does); 30-60 s or longer for a background widget. Don't go
  below ~1 s. There is no push, WebSocket or long-poll.
- The server is small: requests are handled one at a time, about 7
  connections at most (least recently used ones get closed). Use short
  timeouts (~3-5 s) and don't fire requests in parallel.
- Everything is local: the device doesn't cache per client, and each
  `/api/status` builds a fresh response from what's in memory.
- **Unknown fields**: new fields may be added; ignore ones you don't know.
  A removed or renamed field changes `status.example.json` in this repo.
- No history is available from the device. The readings also go to the
  home InfluxDB/Grafana dashboard (see `server/README.md`), but that's
  separate and not part of this API.

## Trying it out

```sh
curl http://desk.local/api/status
curl -X POST "http://desk.local/api/screen?go=air"
curl -X POST "http://desk.local/api/panel?set=toggle"
avahi-browse -rt _http._tcp   # Linux: shows the "Desk display" service
```

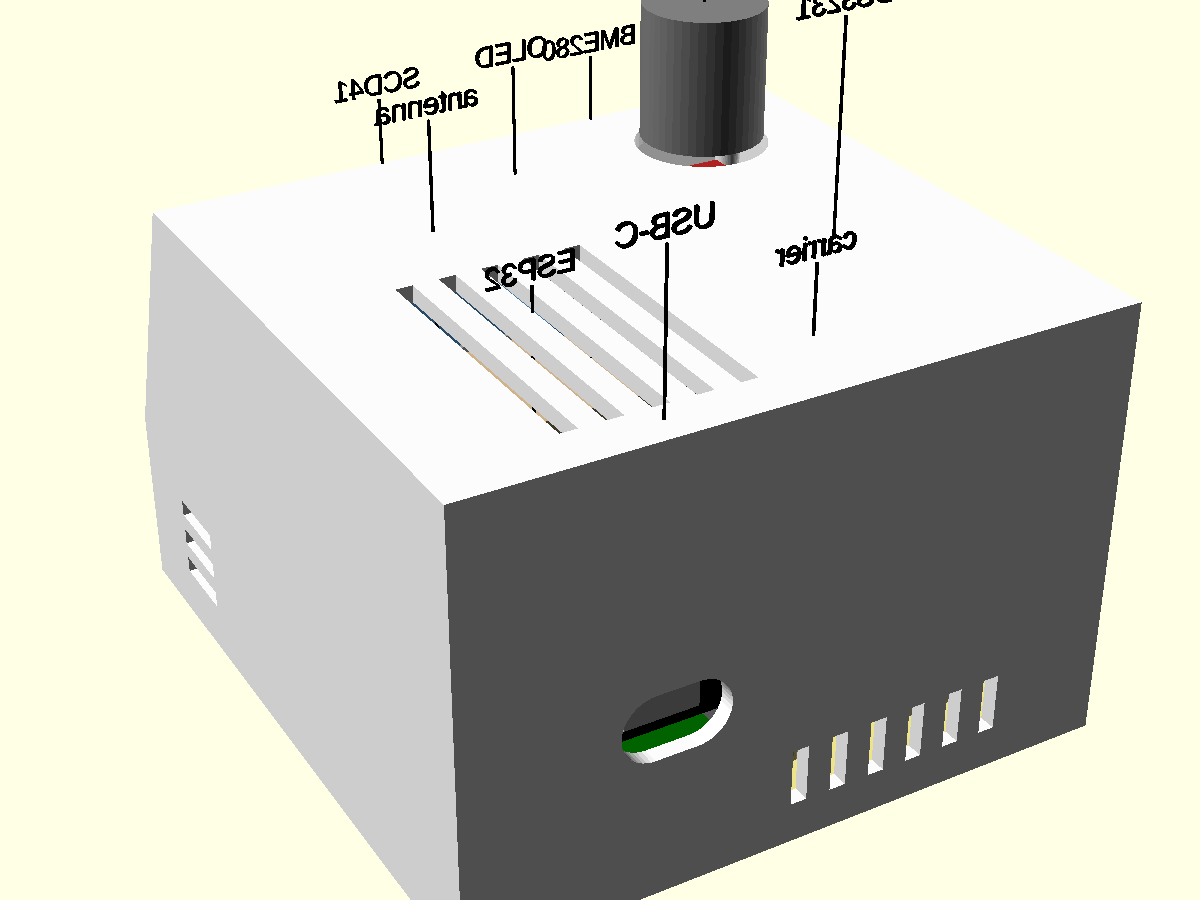
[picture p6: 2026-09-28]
enclosure/renders/enclosure_v2-cut-back.png

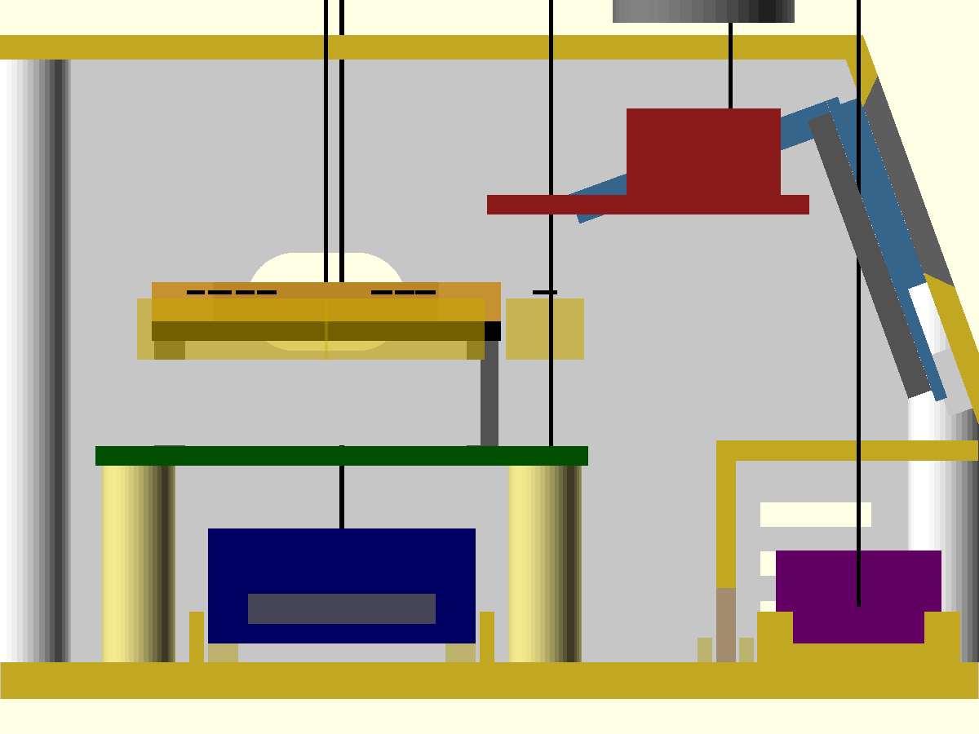
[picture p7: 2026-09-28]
enclosure/renders/enclosure_v2-whole-section.png

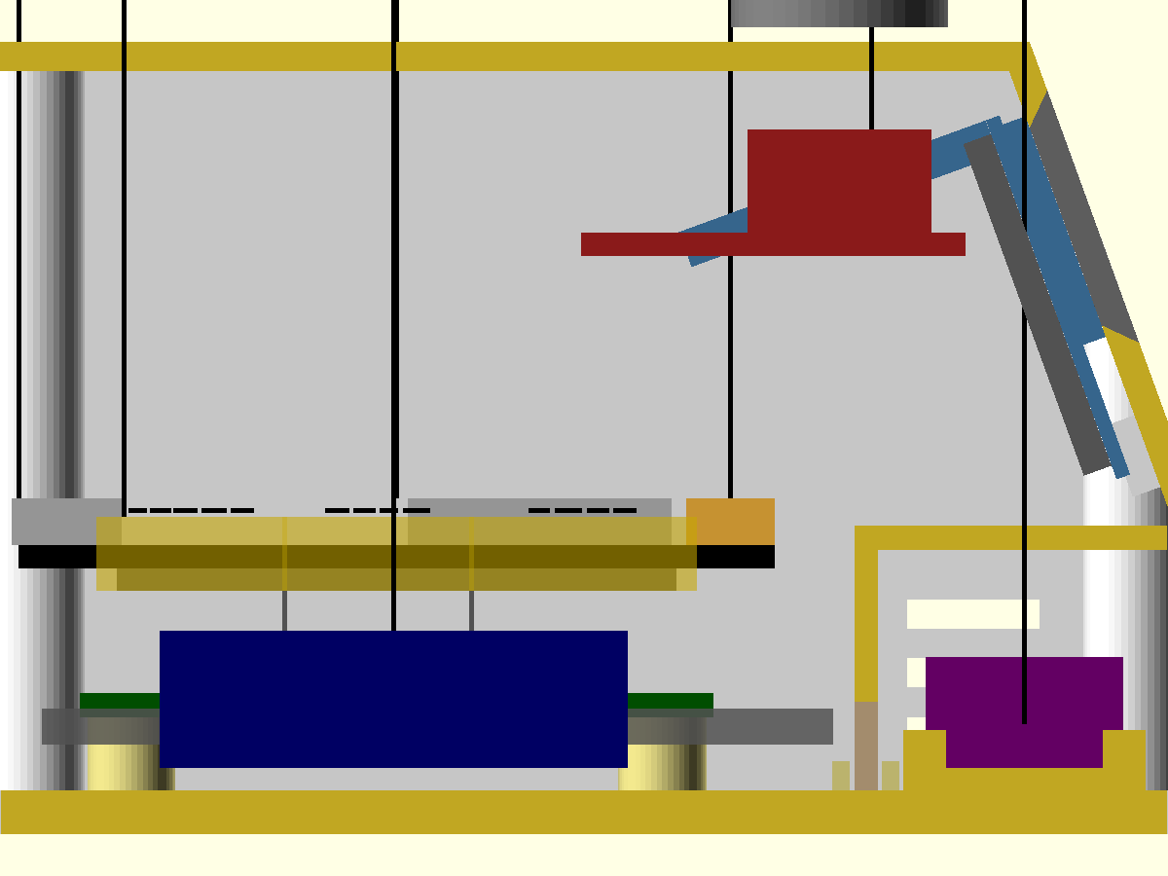
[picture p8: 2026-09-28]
enclosure/renders/enclosure_v2-cut-section.png

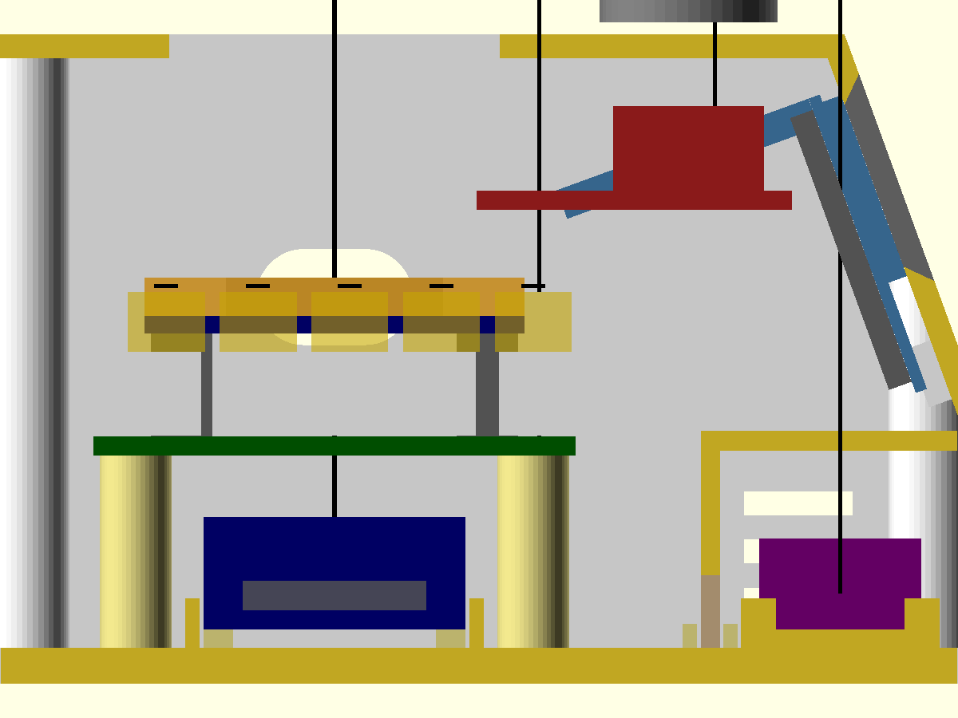
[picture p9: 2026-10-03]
enclosure/renders/enclosure_v3-section.png

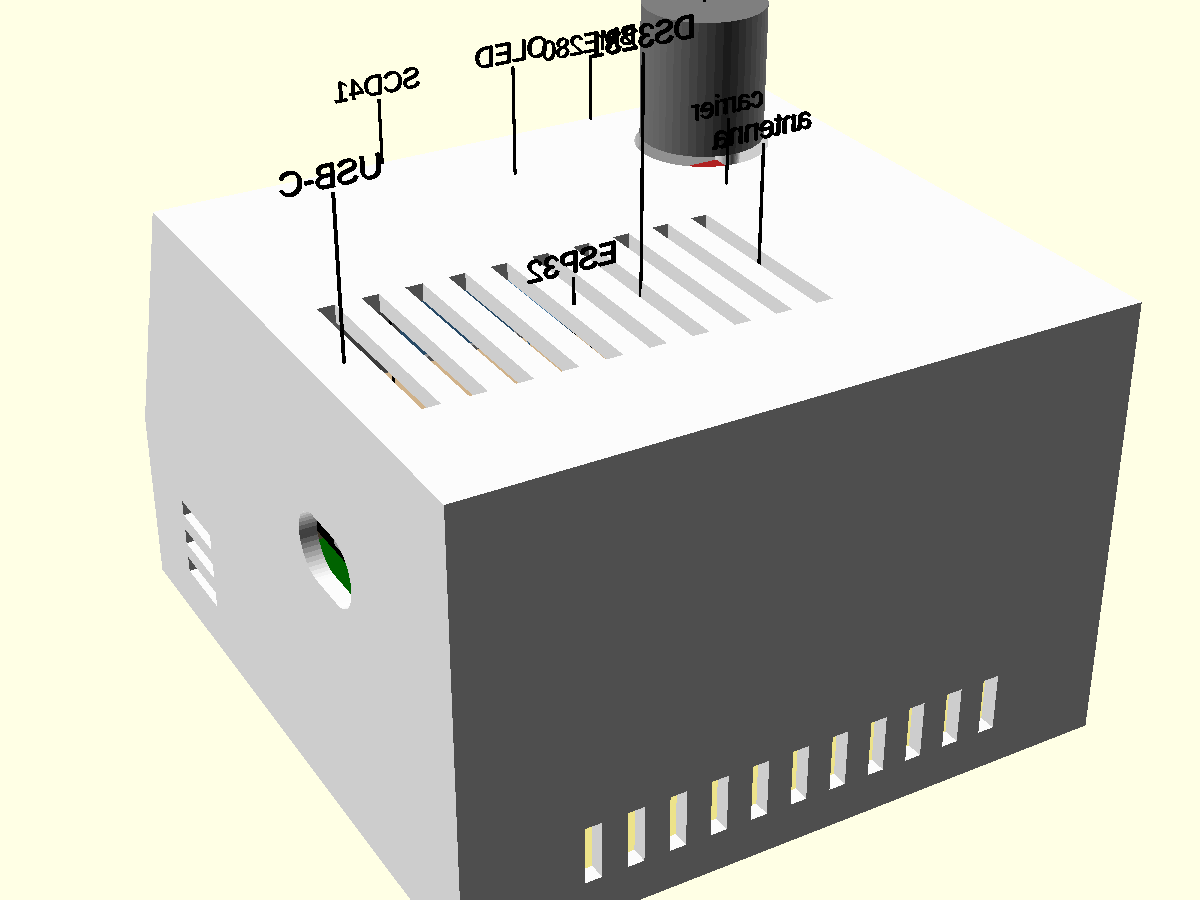
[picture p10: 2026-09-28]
enclosure/renders/enclosure_v2-whole-back.png

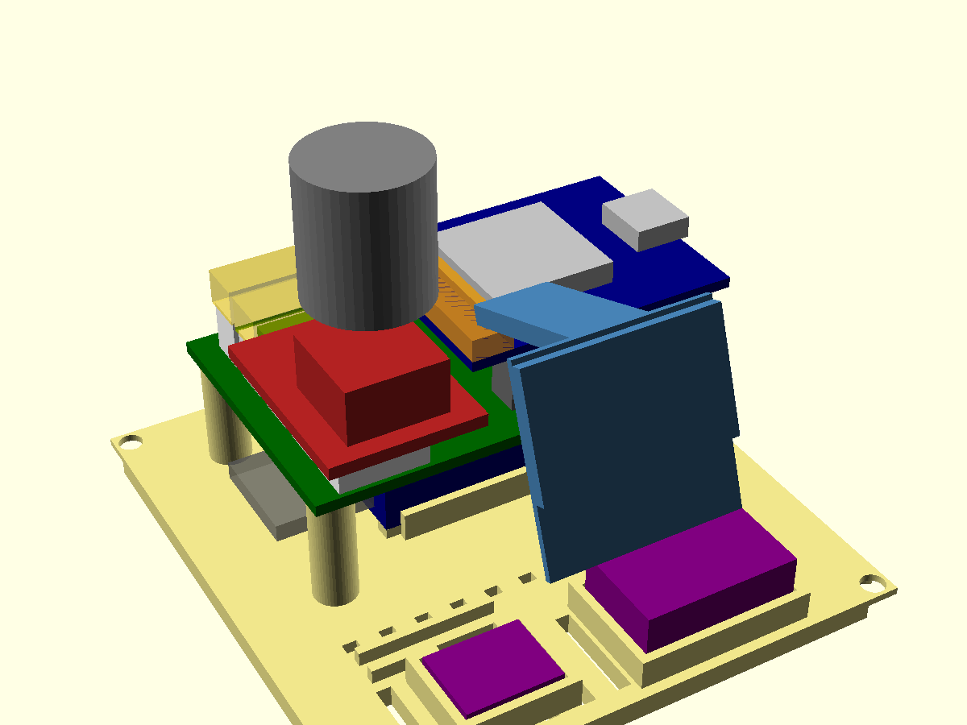
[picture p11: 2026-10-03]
enclosure/renders/enclosure_v3-open.png

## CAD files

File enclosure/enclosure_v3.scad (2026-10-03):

// Desk display enclosure, v3 (ROADMAP task 15): v2's `whole` layout with
// the ESP32 DevKit swapped for the ESP32 mini (D1 mini layout, 31.5 x 39 mm,
// decided 2026-10-03). The 4 x 6 cm perfboard stays uncut, the mini lies
// left-to-right with its USB-C out the right side, plugged into four 10-pin
// female headers. Its antenna end points left, over the carrier, ~5 mm
// from the nearest socket; all five JST-XH sockets sit in a stack at the
// carrier's left end. DS3231 on the floor under the carrier, as in v2.
// enclosure_v2.scad (DevKit) is kept for comparison.
// Sizes in mm: modules from their Homebox entries (parts.py show <part>),
// see MEASUREMENTS.md; values marked ASSUMED were not measured.
//
// Axes: X = width, left to right seen from the front; Y = depth, front at
// y = 0; Z = up, table at z = 0 (rubber feet not modelled).
//
// Printed parts:
//   shell - walls, tilted screen panel, top with the knob; open at the bottom
//   base  - floor plate: carrier board standoffs, sensor pockets, 4 screws
//           up into the shell's corner bosses
//   hood  - roof + back wall of the sensor bay, sits on the base
//   clamp - bar holding the OLED against the screen panel, print 2
// Pick one with -D 'part="shell"' (see export.sh). Single parts come out in
// print orientation, "assembly" shows everything in place with stand-in
// blocks for the modules, "clash" is empty when nothing overlaps.

part = "assembly"; // [assembly, shell, base, hood, clamp, test_front, clash]
cut = -1; // assembly only: >= 0 cuts the printed parts away left of this x
show_shell = true; // assembly only: untick to see inside
show_base = true;
show_hood = true;
show_clamps = true;
show_labels = true; // names over the module stand-ins

$fn = 48;
eps = 0.01;

// ------------------------------------------------------------ print
clr = 0.3; // fit clearance between printed parts / around boards

// ------------------------------------------------------------ modules
oled_w = 26.00;
oled_h = 26.04; // pin edge at the top
oled_t = 2.64; // incl. glass
oled_pcb_t = 1.0; // ASSUMED, only used for the stand-in: rest of oled_t is glass
oled_lit_w = 21.93;
oled_lit_h = 11.32;
oled_lit_top = 3.0; // lit area's top edge below the pin edge (+-0.5)
oled_back = 8.25; // header pins + plastic behind the PCB
oled_dupont = 14; // a plugged-in Dupont connector adds this

// ESP32 mini, in its own frame: x across the pin rows (0..esp_w), y along
// them, antenna end at y 0, USB-C end at esp_l
esp_l = 39.02;
esp_w = 31.51;
esp_t = 1.49;
esp_top = 4.66; // board bottom to the top of the metal can
esp_usb_z = 4.61 - 3.12 / 2; // USB-C centre above the board bottom
esp_usb_out = 1.22; // USB-C shell past the board edge
esp_pins = 10; // pads per line
esp_pin_x = [(esp_w - 27.94) / 2, (esp_w - 22.86) / 2, (esp_w + 22.86) / 2, (esp_w + 27.94) / 2]; // outer, inner, inner, outer
esp_pin_edge = 7.33; // antenna edge to the first pad's centre (6.83 to its near side + ~0.5)
esp_antenna = 6; // antenna end: keep clear

ky_l = 26.18;
ky_w = 19.29;
ky_t = 1.6; // ASSUMED
ky_cap_d = 14.78;
ky_shaft_y = 16 - ky_cap_d / 2; // shaft centre from the board's short edge away
                                // from the pins: that edge to the cap's far side
                                // was ~16 (2026-09-28, skewed reading, +-1)
ky_cap_h = 31.79 - 15.58; // cap height
ky_cap_above = 15.58 - ky_t; // board front face to the cap's lower edge
ky_body = 12.5; // EC11 body footprint (ASSUMED, standard part)
ky_body_h = 7; // EC11 body height above the board (ASSUMED)

ds_l = 31.93;
ds_w = 21.79;
ds_h = 9.39;
ds_pins6 = 14; // 6-pin end: right-angle pins + cable soldered on, bent away (ASSUMED)
ds_pins4 = 8; // pass-through 4-pin end: right-angle pins (ASSUMED)

bme_l = 13.15;
bme_w = 10.66;
bme_h = 3;

scd_l = 21.81;
scd_w = 13.49;
scd_h = 7.59;

// carrier board: the Miuzei 4 x 6 cm perfboard (14 x 20 holes), holes
// drilled to match the base's standoffs (lay it on the printed base, mark
// through, drill 2 mm). perf_w = size along X, perf_d = along Y
whole = true; // v2's naming: board uncut, USB-C out the right side
perf_w = 60;
perf_d = 40;
perf_t = 1.6;
perf_standoff = 16; // the DS3231 lies on the floor under it
perf_hole_inset = 3.5;
hdr_h = 8.5; // female header the ESP32 plugs into (ASSUMED: standard)

// ------------------------------------------------------------ case
wall = 2.0;
tilt = 20; // screen panel, back from vertical
skirt_h = 22; // vented strip under the screen, in front of the sensor bay
panel_margin = 4; // screen panel beyond the OLED board, top and bottom
W = 80;
D = 84;
base_t = 3;

panel_len = oled_h + 2 * panel_margin; // along the slope
H = skirt_h + panel_len * cos(tilt);
run = panel_len * sin(tilt); // how far back the panel's top edge is

boss_d = 7;
boss_pilot = 2.5; // M3 self-tapping, 10 deep
boss_in = wall + boss_d / 2 - 1; // centre from the outside; sunk 1 mm into both walls
boss_xy = [[boss_in, boss_in], [W - boss_in, boss_in], [boss_in, D - boss_in], [W - boss_in, D - boss_in]];

// sensor bay: y wall..bay_back, closed by the hood's roof at hood_top
bay_back = 22;
hood_t = 1.6;
hood_top = skirt_h - 1;
bme_xy = [24, 12];
scd_xy = [52, 12];
ledge_h = 1.5; // sensors sit on corner ledges, air flows underneath
rim = 1.2;

// OLED: glass flat against the panel's inner face, located by 4 corner
// stops, pressed on by two printed clamp bars (part "clamp", print 2)
// screwed to posts beside the board. Its corner holes aren't used: the
// glass reaches almost to them, no room for a screw post
oled_v = panel_len / 2; // board centre, up the slope from the skirt's edge
oled_post_x = oled_w / 2 + clr + 2.5; // clamp posts, left and right of the board
oled_post_d = 5;
oled_pilot = 1.6; // M2 x 5 self-tapping
clamp_t = 2;
clamp_overlap = 3; // how far a bar reaches over the board's back, along its side edge
lit_dz = oled_h / 2 - oled_lit_top - oled_lit_h / 2; // lit centre above board centre
win_w = oled_lit_w + 1;
win_h = oled_lit_h + 1;

// knob on top, left: KY-040 board flat under the top, pins to the back,
// held by two snap hooks on its long edges, pushed up against 4 pads
knob_x = 16;
ky_y0 = 16; // board's front edge
knob_y = ky_y0 + ky_shaft_y;
knob_gap = 1; // top surface to the cap's lower edge
knob_hole = 16;
ky_face_z = H + knob_gap - ky_cap_above; // board front (component) face
ky_back_z = ky_face_z - ky_t;

// Everything on the carrier sits on its 2.54 hole grid: hole (col, row) is
// at [grid_x0 + col * p, grid_y0 + row * p]. The board has 14 x 20 holes,
// ASSUMED centred (margins 3.49 across 14, 5.87 along 20).
p = 2.54;
usb_gap = 1.5; // USB-C shell to the wall
// 20 cols along X, 14 rows across Y. The mini's four pad lines run along X
// in rows 1, 2, 11, 12, pads in cols 10-19, USB end hanging ~3 mm off the
// right edge. Cols 0-4 hold the sockets; the antenna starts at col ~7
esp_x0 = W - wall - usb_gap - esp_usb_out - esp_l;
grid_x0 = esp_x0 + esp_pin_edge - 10 * p;
grid_y0 = D - wall - boss_d - 1 - 40 + 3.49;
perf_x0 = grid_x0 - 5.87;
perf_y0 = grid_y0 - 3.49;
perf_x1 = perf_x0 + perf_w;
perf_y1 = perf_y0 + perf_d;
perf_z = base_t + perf_standoff;
esp_y1 = grid_y0 + 12 * p + esp_pin_x[0]; // outer line nearest the back in row 12
esp_y0 = esp_y1 - esp_w;
esp_x1 = esp_x0 + esp_l;
esp_z = perf_z + perf_t + hdr_h; // mini board bottom
usb_x = (esp_x0 + esp_x1) / 2;
usb_y = (esp_y0 + esp_y1) / 2; // hole in the right wall (socket ~0.25 off centre: ignored)
usb_z = esp_z + esp_usb_z;
usb_hole = [13, 8];

// DS3231, on the floor in a holder, coin cell up. Box ds_b = [x0, y0, x1, y1]
// is the board; its pins stick out of both short ends. cut: long axis
// front-to-back, 6-pin end to the front. whole: long axis left-to-right
// under the carrier, 6-pin end to the left
ds_z = base_t + ledge_h;
ds_b = whole ? [26, (perf_y0 + perf_y1) / 2 - ds_w / 2, 26 + ds_l, (perf_y0 + perf_y1) / 2 + ds_w / 2]
             : [perf_x0 - rim - clr - 1 - ds_w, 39, perf_x0 - rim - clr - 1, 39 + ds_l];

echo(str("case ", W, " x ", D, " x ", H, " mm (W x D x H)"));
echo(str("usb centre z ", usb_z, ", knob board face z ", ky_face_z));
assert(perf_x1 < W - wall && perf_y1 < D - wall, "carrier hits a wall");
assert(esp_x1 + esp_usb_out < W - wall && esp_y1 < D - wall, "ESP32 hits a wall");
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

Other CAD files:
enclosure/enclosure.scad
enclosure/enclosure_v2.scad

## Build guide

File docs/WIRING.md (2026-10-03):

# Wiring

All modules share the ESP32's 3V3 and GND. Never 5V/VIN (see "Power & bus
budget" in `CLAUDE.md` for this build's total). Everything is currently on a solderless
breadboard; the soldered carrier board comes with the enclosure (ROADMAP
task 15).

Wire colours: 🟢 green = D21 (SDA), 🟡 yellow = D22 (SCL).

| Module | Module pin | ESP32 pin | Notes |
|---|---|---|---|
| OLED SSD1315 | VCC | 3V3 | |
| | GND | GND | |
| | SDA | 🟢 D21 | I2C, addr 0x3C |
| | SCL | 🟡 D22 | |
| DS3231 RTC (6-pin header) | VCC | 3V3 | not 5V: coin-cell charging circuit |
| | GND | GND | |
| | SDA | 🟢 D21 | I2C, addr 0x68 (+0x57 EEPROM, 0x5F) |
| | SCL | 🟡 D22 | |
| | 32K, SQW | — | unconnected |
| BME280 | VIN | 3V3 | |
| | GND | GND | |
| | SDA | 🟢 D21 | I2C, addr 0x76 |
| | SCL | 🟡 D22 | |
| SCD41 CO2 | GND | GND | pin order on the module: GND, VDD, SCL, SDA |
| | VDD | 3V3 | |
| | SCL | 🟡 D22 | I2C, addr 0x62 |
| | SDA | 🟢 D21 | |
| KY-040 encoder | + | 3V3 | onboard 10k pull-ups go to this pin |
| | GND | GND | |
| | SW | D27 | button, active low |
| | DT | D26 | |
| | CLK | D25 | |

- Part facts (module pin order, addresses, current draw, the DevKit's pin order)
  are in each part's Homebox entry (`python3
  ../grappim-watcher/docs/esp32/inventory/parts.py show <part>`); GPIO, power and I2C rules in
  `../grappim-watcher/docs/esp32/WIRING_RULES.md`. This file is only this
  build's pin table.
- I2C modules are wired **in parallel** straight to D21/D22 (rule and the
  failed daisy-chain: `WIRING_RULES.md` there, and the DS3231's Homebox entry).
- KY-040: male-female Dupont cable from the breadboard to the knob, in the
  module's pin order, so it can sit apart from the board. The encoder pins can
  move to D18/D19/D23 if a board redesign makes the right side more convenient.
- An LDR divider sat on D34 briefly on 2026-09-25; removed again, see ROADMAP
  task 5.
- Free, non-strapping GPIOs for future modules: D4, D16, D17, D18, D19, D23,
  D32, D33 (plus the input-only D34/D35/VP/VN).

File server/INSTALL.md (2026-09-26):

# Installing the dashboard server on a machine

Step-by-step for whoever sets this up on the always-on home machine (a
person or a Claude Code session there). Background on what it is:
`README.md` next to this file.

**Goal:** InfluxDB + Grafana running in Docker on a machine that is on the
**same WiFi/LAN as the desk display** (an ESP32), reachable on ports 34898
(InfluxDB, the display writes there) and 34897 (the dashboard). The ports
are deliberately not the defaults (8086/3000). At the end, hand back
two values: the machine's **LAN IP** and the **InfluxDB token**.

Nothing here touches the ESP32 firmware; that side is done from the
desk-display repo on the dev machine once the two values are known.

## 1. Check prerequisites

```sh
docker --version && docker compose version   # both must work
ip -4 -o addr show | awk '{print $2, $4}'    # find the LAN address
```

- The LAN IP is the one on the home network (typically `192.168.x.x` on
  the ethernet/WiFi interface), **not** `tailscale0` (100.x), `docker0` or
  `br-*`. The ESP32 can't use Tailscale.
- Check the ports are free: `ss -ltn | grep -E ":(34897|34898)\b"` should
  print nothing. If something already uses them, stop and ask the user
  (the ports are set in `docker-compose.yml`; changing the InfluxDB one
  means changing `METRICS_PORT` in the firmware's `main/metrics.c` too).

## 2. Get the files

Only the `server/` folder is needed. The repo is public:

```sh
git clone --depth 1 https://github.com/Grigoriym/esp32-desk-display.git ~/esp32-desk-display
cd ~/esp32-desk-display/server
```

(If the user prefers another location or already keeps compose stacks in a
certain folder, put it there instead: the folder only needs `server/`'s
contents.)

## 3. Create `.env`

```sh
cp .env.example .env
```

Fill in both values in `.env`:

- `INFLUX_TOKEN`: if the user gave you a token (e.g. the one the display is
  already flashed with), use it. Otherwise generate one:
  `openssl rand -hex 32`.
- `INFLUX_ADMIN_PASSWORD`: any password, e.g. `openssl rand -hex 12`.
  It's the login for Grafana's and InfluxDB's admin UIs.

`.env` is gitignored; never commit it.

## 4. Start it

```sh
docker compose up -d
docker compose ps        # both influxdb and grafana: running
```

The first start creates the `desk` org and bucket and the token from
`.env`. Those settings only apply on the **first** start: if `.env` is
changed later, the old token stays valid and the new one isn't created.
Starting over means `docker compose down -v` (deletes all stored data).

## 5. Verify

Run from this directory (reads the token from `.env`):

```sh
. ./.env
curl -s -o /dev/null -w "influx %{http_code}\n" localhost:34898/health        # 200
curl -s -o /dev/null -w "grafana %{http_code}\n" localhost:34897/api/health   # 200

# A test write with the token, exactly like the display does it (expect 204),
# then delete it again (expect 204):
curl -s -o /dev/null -w "write %{http_code}\n" -X POST \
  "http://localhost:34898/api/v2/write?org=desk&bucket=desk&precision=s" \
  -H "Authorization: Token $INFLUX_TOKEN" --data-binary 'indoor,device=test temp_c=20'
curl -s -o /dev/null -w "delete %{http_code}\n" -X POST \
  "http://localhost:34898/api/v2/delete?org=desk&bucket=desk" \
  -H "Authorization: Token $INFLUX_TOKEN" -H 'Content-Type: application/json' \
  -d '{"start":"2020-01-01T00:00:00Z","stop":"2100-01-01T00:00:00Z","predicate":"device=\"test\""}'
```

Then check it's reachable **from the LAN**, not just locally: from another
device on the home network (or ask the user to open it on their phone),
`http://<LAN IP>:34897` should show the "Desk display" dashboard without a
login. If it only works locally, a firewall is blocking it:

```sh
sudo ufw status            # if active:
sudo ufw allow from 192.168.0.0/16 to any port 34898 proto tcp
sudo ufw allow from 192.168.0.0/16 to any port 34897 proto tcp
```

(Use the actual home subnet. Don't open these ports to the internet: the
dashboard has anonymous read access and the write API is plain HTTP.)

## 6. Hand back

Tell the user, for the desk-display session on the dev machine:

- `METRICS_HOST` = the LAN IP from step 1
- `METRICS_TOKEN` = `INFLUX_TOKEN` from `.env`

Those go into the gitignored `main/metrics_secrets.h` there, then the
firmware is rebuilt and flashed. The display's boot log then shows
`metrics: upload OK` about a minute after start, and the dashboard fills
in from then on.

Recommend a **fixed IP** for this machine (a DHCP reservation in the
router): the IP is compiled into the firmware, so if it changes the
display silently stops uploading.

## Maintenance

- **Take repo updates** (new dashboard panels etc.): `git pull` in the
  clone. `grafana/dashboards/desk.json` is committed, so Grafana just
  reloads it within ~10 s: no regenerating, no restart. Only if the pull
  changed `docker-compose.yml`: `docker compose up -d`. Check: the
  dashboard at `http://<LAN IP>:34897` shows the new panels.

- Update the images: `docker compose pull && docker compose up -d`
  (versions are pinned to `influxdb:2.9` and `grafana/grafana:13.2` in
  `docker-compose.yml`; data survives in named volumes).
- Logs: `docker compose logs -f grafana` / `influxdb`.
- Dashboard changes: edit `grafana/make_dashboard.py` and run it
  (`python3 grafana/make_dashboard.py`, regenerates
  `grafana/dashboards/desk.json`, Grafana reloads it within ~10 s); edits
  made in the Grafana UI are not saved for this dashboard.
- Stop: `docker compose down` (keeps data); `down -v` wipes it.

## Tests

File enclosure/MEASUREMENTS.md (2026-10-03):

# Part measurements (ROADMAP task 15)

The caliper measurements of each part (in mm) live only in the part's
Homebox entry (fields "Board size", "Mounting holes", ...): read them with
`python3 ../../grappim-watcher/docs/esp32/inventory/parts.py show <part>`.
The OpenSCAD model is written from those numbers, not from datasheet
guesses. A new or corrected measurement goes in the entry, not here.

Measured 2026-09-28: OLED (SSD1315), ESP32 DevKit 30-pin, KY-040, DS3231,
BME280, SCD41. Measured 2026-10-03 (battery, not in the model yet): LiPo
103745, FM5324 charge module, USB-C breakout.

How to measure: `../../grappim-watcher/docs/esp32/ENCLOSURE_PLAYBOOK.md`.

## This case's choices
- KY-040 (2026-09-28): the knob **cap** sticks out through a round hole in the
  case and the board sits behind the panel, so shaft/collar sizes aren't needed.
  Top hole 16 mm.
- DS3231: its mounting holes aren't used.
- USB-C cable: an ordinary one, not measured. Rear hole **13 x 8, rounded ends**.
- Case size: as small as the parts allow (no preference given)
- Screen tilt: ~20 degrees (default)
- Printer material: ask the printing person; PETG preferred, clearance 0.2-0.3 assumed
- Battery: **not in the MVP** (2026-09-28). Planned later (see CLAUDE.md Open
  questions), so keep the case easy to open and don't pack it so tight a small
  cell can never fit

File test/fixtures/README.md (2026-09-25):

# Test fixtures

- `weather_ok.json`: real Open-Meteo response, captured 2026-09-25 13:09 with the
  exact URL from `main/weather.c` (dry: rain chance at most 10% over the 12 h).
- `air_ok.json`: real Open-Meteo air-quality response, captured 2026-09-25
  14:00 with the exact `AIR_URL` from `main/weather.c` (off season: pollen
  all ~0, only the AQI says much).
- `alerts_none.json`: real Bright Sky `/alerts` response, captured
  2026-09-25 with the exact `ALERTS_URL` from `main/weather.c`: no warnings
  out (none anywhere in Germany that day).
- `alerts_warnings.json`: **hand-written** from the Bright Sky schema
  (`api.brightsky.dev/openapi.json`) and the English DWD labels in
  dwdparse's CAP test data (`heavy rain`, `wind gusts`): two started
  warnings, an upcoming severe one and a `status: test` message. Replace
  with a real capture the next time Berlin has a warning.
- `holidays_2026.json`: real Nager.Date response for 2026/DE, captured
  2026-09-25 (19 entries, 10 apply in Berlin).
- `bvg_real.json`: real transport.rest response, captured 2026-09-25 10:29
  with the URL from `main/bvg.c` (U Cottbusser Platz, U5 towards Hbf):
  6 departures every 10 min, no delays or cancellations.
- `bvg_ok.json`: **hand-written** in the same format (the wrapper was down
  when the tests were first written); kept because it covers what the real
  capture doesn't: a delayed trip, a cancelled one (`"when": null`), a
  " (Berlin)" suffix and a trip after midnight. Replace both with VBB
  responses once roadmap task 4b switches APIs.

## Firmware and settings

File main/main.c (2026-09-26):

#include <stdio.h>
#include <string.h>
#include <math.h>
#include "esp_log.h"
#include "esp_system.h"
#include "freertos/FreeRTOS.h"
#include "freertos/task.h"
#include "driver/i2c_master.h"
#include "display.h"
#include "wifi.h"
#include "clock.h"
#include "weather.h"
#include "holidays.h"
#include "bme280.h"
#include "scd41.h"
#include "encoder.h"
#include "bvg.h"
#include "screens.h"
#include "health.h"
#include "metrics.h"
#include "metrics_format.h"
#include "web.h"
#include "bvg_secrets.h"
#include <time.h>

static const char *TAG = "desk_display";

#define I2C_SDA_GPIO GPIO_NUM_21
#define I2C_SCL_GPIO GPIO_NUM_22
#define I2C_PORT     I2C_NUM_0

#define WIFI_CONNECT_TIMEOUT_SECONDS 15
#define NTP_RETRY_SECONDS            60

// Boot status grid: two columns, local hardware on top, network below.
// Each item is a (page, column) cell; column 0 = left, 1 = right.
#define SPLASH_OLED    2, 0
#define SPLASH_PWR     2, 1
#define SPLASH_RTC     3, 0
#define SPLASH_BME     3, 1
#define SPLASH_WIFI    5, 0
#define SPLASH_NTP     5, 1
#define SPLASH_WEATHER 6, 0
#define SPLASH_CO2     6, 1

// Main screens (see screens.h). The clock row sits on page 0 of every
// screen; draw_screen() owns pages 1-7.
#define PAGE_CLOCK 0 // time left, date right

static screen_t s_screen;
static bool s_panel_on = true; // knob press toggles it
static screen_data_t s_data = {
    .bvg_walk_min = BVG_WALK_MIN_MINUTES,
    .bvg_walk_comfort = BVG_WALK_COMFORT_MINUTES,
};

// Everything that's allowed to answer on the I2C bus. Anything else showing
// up means an address clash or an unplanned module -- see "Power & bus
// budget" in CLAUDE.md before wiring a new one, then add it here.
static const struct {
    uint8_t addr;
    const char *name;
} KNOWN_I2C[] = {
    {0x3C, "OLED"},
    {0x3D, "OLED (alt addr)"},
    {0x57, "DS3231 EEPROM (AT24C32)"},
    {0x5F, "DS3231 module extra addr"},
    {0x62, "SCD41 CO2"},
    {0x68, "DS3231 RTC"},
    {0x76, "BME280"},
    {0x77, "BME280 (alt addr)"},
};

// One "NAME    OK" cell of the boot status grid. Every cell is padded to
// the same width, so the status column lines up within each column.
static void splash_status(int page, int col, const char *name, const char *status)
{
    static char cells[8][2][12];
    snprintf(cells[page][col], sizeof(cells[page][col]), "%-8s%s", name, status);
    ESP_ERROR_CHECK(display_draw_text_columns(page, cells[page][0], cells[page][1]));
}

static void draw_clock_row(void)
{
    char time_str[6];
    char date_str[11];
    clock_format_now(time_str, sizeof(time_str));
    clock_format_date(date_str, sizeof(date_str));
    display_draw_text_columns(PAGE_CLOCK, time_str, date_str);
}

// Redraws pages 1-7 for the current screen. Every page is written in full
// (unused ones blank), so switching screens needs no display_clear() and
// doesn't flicker. Missing data shows as "--".
static void draw_screen(void)
{
    time_t now = time(NULL);
    struct tm t;
    localtime_r(&now, &t);
    screen_rows_t rows;
    screen_layout(s_screen, &s_data, t.tm_hour * 60 + t.tm_min, &rows);

    for (int page = 1; page < 8; page++) {
        const char *left = rows.text[page][0];
        const char *right = rows.text[page][1];
        if (s_screen == SCREEN_HOME && page == 3) {
            // Icon + outdoor temperature, centred together.
            int code = s_data.weather_ok ? s_data.weather.weather_code : 3;
            display_draw_icon_and_text(page, weather_icon_for_code(code), left);
        } else if (right[0]) {
            display_draw_text_columns(page, left, right);
        } else {
            display_draw_text(page, left); // centred; "" blanks the page
        }
    }
}

// Logs every device on the bus and warns about any not in KNOWN_I2C.
// Missing required devices already show up as OLED/RTC failures.
static void i2c_bus_check(i2c_master_bus_handle_t bus)
{
    int found = 0;
    for (uint8_t addr = 0x08; addr < 0x78; addr++) {
        if (i2c_master_probe(bus, addr, 20) != ESP_OK) continue;
        found++;
        const char *name = NULL;
        for (size_t i = 0; i < sizeof(KNOWN_I2C) / sizeof(KNOWN_I2C[0]); i++) {
            if (KNOWN_I2C[i].addr == addr) name = KNOWN_I2C[i].name;
        }
        if (name) {
            ESP_LOGI(TAG, "I2C 0x%02X: %s", addr, name);
        } else {
            ESP_LOGW(TAG, "I2C 0x%02X: UNKNOWN device -- address clash or unplanned module?", addr);
        }
    }
    ESP_LOGI(TAG, "I2C bus: %d address(es) answering", found);
}

// NTP can transiently fail right after WiFi comes up (DNS/AP not fully
// settled yet). Retry with backoff instead of ESP_ERROR_CHECK-ing straight
// into a crash/reboot loop over what's usually a few-second hiccup.
static esp_err_t ntp_sync_with_retry(void)
{
    const int max_attempts = 5;
    int backoff_s = 2;
    for (int attempt = 1; attempt <= max_attempts; attempt++) {
        esp_err_t err = clock_sync_time();
        if (err == ESP_OK) return ESP_OK;
        ESP_LOGW(TAG, "NTP sync attempt %d/%d failed: %s", attempt, max_attempts, esp_err_to_name(err));
        if (attempt < max_attempts) {
            vTaskDelay(pdMS_TO_TICKS(backoff_s * 1000));
            backoff_s *= 2;
        }
    }
    return ESP_FAIL;
}

#define WEATHER_REFRESH_SECONDS     (15 * 60)
#define WEATHER_RETRY_START_SECONDS 30
#define INDOOR_REFRESH_SECONDS      10
#define CO2_POLL_SECONDS            5 // the sensor itself measures every 30 s
#define HEALTH_LOG_SECONDS          (5 * 60)
#define METRICS_SECONDS             60
#define HOLIDAYS_RETRY_SECONDS      (30 * 60)

// What the boot sequence found out, and the main loop's timers.
typedef struct {
    bool indoor_present; // BME280 found at boot
    bool co2_present;    // SCD41 found at boot
    bool ntp_ok;
    int seconds_since_weather;
    int next_weather_interval; // shortened after a failure, see tick_weather()
    int seconds_since_indoor;
    int seconds_since_co2;
    int seconds_since_ntp;
    int seconds_since_health;
    int seconds_since_metrics;
    int seconds_since_holidays;
    int last_minute;
} app_state_t;

static i2c_master_bus_handle_t i2c_init(void)
{
    i2c_master_bus_config_t bus_cfg = {
        .i2c_port = I2C_PORT,
        .sda_io_num = I2C_SDA_GPIO,
        .scl_io_num = I2C_SCL_GPIO,
        .clk_source = I2C_CLK_SRC_DEFAULT,
        .glitch_ignore_cnt = 7,
        .flags.enable_internal_pullup = true,
    };
    i2c_master_bus_handle_t bus;
    ESP_ERROR_CHECK(i2c_new_master_bus(&bus_cfg, &bus));
    return bus;
}

// A brownout reset means the supply sagged below ~2.4V: too much load on the
// 3.3V rail or a weak USB port/cable. Shown as "PWR NO" at boot.
static bool last_reset_was_brownout(void)
{
    esp_reset_reason_t reset_reason = esp_reset_reason();
    if (reset_reason == ESP_RST_BROWNOUT) {
        ESP_LOGE(TAG, "last reset was a BROWNOUT -- check power budget in CLAUDE.md");
        return true;
    }
    ESP_LOGI(TAG, "reset reason: %d", reset_reason);
    return false;
}

// Boot status screen: lights the panel right away and shows each subsystem
// coming up, instead of a blank screen for ~6-8s.
static void splash_begin(bool brownout)
{
    ESP_ERROR_CHECK(display_draw_text(0, "HELLO"));
    splash_status(SPLASH_OLED, "OLED", "OK"); // if this is visible, it works
    splash_status(SPLASH_PWR, "PWR", brownout ? "NO" : "OK");
    splash_status(SPLASH_RTC, "RTC", "--");
    splash_status(SPLASH_BME, "BME", "--");
    splash_status(SPLASH_WIFI, "WIFI", "--");
    splash_status(SPLASH_NTP, "NTP", "--");
    splash_status(SPLASH_WEATHER, "WEATHER", "--");
    splash_status(SPLASH_CO2, "CO2", "--");
}

// Local hardware: RTC first, so the clock is right even if NTP fails later.
// The BME280 and SCD41 are optional; their screen rows just stay "--" without them.
static void boot_local(i2c_master_bus_handle_t bus, app_state_t *st)
{
    esp_err_t rerr = clock_rtc_init(bus);
    if (rerr != ESP_OK) ESP_LOGW(TAG, "RTC not used: %s", esp_err_to_name(rerr));
    splash_status(SPLASH_RTC, "RTC", rerr == ESP_OK ? "OK" : "NO");

    esp_err_t berr = bme280_init(bus);
    if (berr != ESP_OK) ESP_LOGW(TAG, "BME280 not used: %s", esp_err_to_name(berr));
    splash_status(SPLASH_BME, "BME", berr == ESP_OK ? "OK" : "NO");
    st->indoor_present = (berr == ESP_OK);

    esp_err_t cerr = scd41_init(bus);
    if (cerr != ESP_OK) ESP_LOGW(TAG, "SCD41 not used: %s", esp_err_to_name(cerr));
    splash_status(SPLASH_CO2, "CO2", cerr == ESP_OK ? "OK" : "NO");
    st->co2_present = (cerr == ESP_OK);
}

// Fetches the weather, air quality and DWD warnings into s_data; returns
// whether all three worked.
static bool fetch_weather(const char *what)
{
    weather_t weather;
    esp_err_t err = weather_fetch(&weather);
    if (err != ESP_OK) {
        ESP_LOGW(TAG, "weather %s failed: %s", what, esp_err_to_name(err));
        return false;
    }
    ESP_LOGI(TAG, "weather %s (%dC, wind %dkm/h, UV %d, sun %s-%s, rain in %dh from %s till %s)", what,
             weather.temp_c, weather.wind_kmh, weather.uv_max, weather.sunrise, weather.sunset,
             weather.rain_in_h, weather.rain_from, weather.rain_until);
    s_data.weather = weather;
    s_data.weather_ok = true;

    // Air quality rides along on the same cadence; a failure keeps the last
    // reading and makes the whole fetch count as failed, so it's retried soon.
    air_t air;
    err = air_fetch(&air);
    if (err != ESP_OK) {
        ESP_LOGW(TAG, "air %s failed: %s", what, esp_err_to_name(err));
        return false;
    }
    ESP_LOGI(TAG, "air %s (AQI %d, pollen alder %d birch %d grass %d mugwort %d ragweed %d)", what, air.aqi,
             air.pollen[POLLEN_ALDER], air.pollen[POLLEN_BIRCH], air.pollen[POLLEN_GRASS],
             air.pollen[POLLEN_MUGWORT], air.pollen[POLLEN_RAGWEED]);
    s_data.air = air;
    s_data.air_ok = true;

    // Warnings too, but a failure drops them instead of keeping the last
    // ones: a stale warning on screen is worse than none.
    char now_local[17];
    time_t now = time(NULL);
    struct tm now_tm;
    localtime_r(&now, &now_tm);
    strftime(now_local, sizeof(now_local), "%Y-%m-%dT%H:%M", &now_tm);
    alerts_t alerts;
    err = alerts_fetch(now_local, &alerts);
    s_data.alerts_ok = (err == ESP_OK);
    if (err != ESP_OK) {
        ESP_LOGW(TAG, "alerts %s failed: %s", what, esp_err_to_name(err));
        return false;
    }
    if (alerts.count > 0) {
        ESP_LOGI(TAG, "alerts %s (%d, showing %s, severity %d, %s %s)", what, alerts.count, alerts.event,
                 (int)alerts.severity, alerts.started ? "since" : "from", alerts.onset);
    } else {
        ESP_LOGI(TAG, "alerts %s (none)", what);
    }
    s_data.alerts = alerts;
    return true;
}

// Network: bounded WiFi wait. With no network the clock still comes up on RTC
// time and WiFi keeps reconnecting in the background; NTP and weather catch
// up in the main loop once it connects.
static void boot_network(app_state_t *st)
{
    esp_err_t wferr = wifi_connect(WIFI_CONNECT_TIMEOUT_SECONDS * 1000);
    splash_status(SPLASH_WIFI, "WIFI", wferr == ESP_OK ? "OK" : "NO");

    bool weather_ok = false;
    if (wferr == ESP_OK) {
        ESP_LOGI(TAG, "WiFi connected");
        st->ntp_ok = (ntp_sync_with_retry() == ESP_OK);
        if (st->ntp_ok) ESP_LOGI(TAG, "NTP synced");
        else ESP_LOGE(TAG, "NTP sync failed after retries, continuing with unsynced clock");
        splash_status(SPLASH_NTP, "NTP", st->ntp_ok ? "OK" : "NO");
        weather_ok = fetch_weather("fetched");
    } else {
        ESP_LOGW(TAG, "no WiFi, skipping NTP and weather for now");
        splash_status(SPLASH_NTP, "NTP", "NO");
    }
    splash_status(SPLASH_WEATHER, "WEATHER", weather_ok ? "OK" : "NO");
    // On failure, retry sooner than the normal cadence and back off toward
    // it, instead of leaving a stale reading up for a full 15 minutes.
    st->next_weather_interval = weather_ok ? WEATHER_REFRESH_SECONDS : WEATHER_RETRY_START_SECONDS;
}

// Background parts that don't block boot.
static void start_background(void)
{
    esp_err_t bverr = bvg_start();
    if (bverr != ESP_OK) ESP_LOGW(TAG, "BVG not used: %s", esp_err_to_name(bverr));
    esp_err_t eerr = encoder_init();
    if (eerr != ESP_OK) ESP_LOGW(TAG, "encoder not used: %s", esp_err_to_name(eerr));
    esp_err_t merr = metrics_start();
    if (merr != ESP_OK) ESP_LOGI(TAG, "dashboard upload off: %s", esp_err_to_name(merr));
    esp_err_t werr = web_start();
    if (werr != ESP_OK) ESP_LOGW(TAG, "web API not used: %s", esp_err_to_name(werr));
}

// The per-second jobs below return true when the screen needs a redraw.

// Minute-based text (BVG countdown) goes stale on the minute.
static bool tick_minute(app_state_t *st)
{
    time_t now = time(NULL);
    struct tm now_tm;
    localtime_r(&now, &now_tm);
    if (now_tm.tm_min == st->last_minute) return false;
    st->last_minute = now_tm.tm_min;
    // Before NTP/RTC the clock says 1970: no date to match holidays against.
    s_data.today_ymd = now_tm.tm_year + 1900 >= 2025
                           ? (now_tm.tm_year + 1900) * 10000 + (now_tm.tm_mon + 1) * 100 + now_tm.tm_mday
                           : 0;
    return true;
}

// Departures are fetched in the background, only while their screen is up
// or a phone is reading the web API; set from the 1s tick so spinning past
// the screen doesn't fetch.
static bool tick_bvg(void)
{
    bvg_set_active(s_screen == SCREEN_BVG || web_recently_polled());
    return bvg_take_update(&s_data.bvg, &s_data.bvg_ok, &s_data.bvg_failed);
}

static bool tick_indoor(app_state_t *st)
{
    if (!st->indoor_present || ++st->seconds_since_indoor < INDOOR_REFRESH_SECONDS) return false;
    st->seconds_since_indoor = 0;
    bme280_reading_t r;
    if (bme280_read(&r) != ESP_OK) {
        ESP_LOGW(TAG, "BME280 read failed");
        return false;
    }
    ESP_LOGI(TAG, "indoor %.1fC %.0f%% %.1fhPa", r.temp_c, r.humidity_pct, r.pressure_hpa);
    s_data.indoor = r;
    s_data.indoor_ok = true;
    return true;
}

// Asks the SCD41 for a new reading every few seconds; it has one every 30 s.
static bool tick_co2(app_state_t *st)
{
    if (!st->co2_present || ++st->seconds_since_co2 < CO2_POLL_SECONDS) return false;
    st->seconds_since_co2 = 0;
    scd41_reading_t r;
    esp_err_t err = scd41_read(&r);
    if (err == ESP_ERR_NOT_FINISHED) return false;
    if (err != ESP_OK) {
        ESP_LOGW(TAG, "SCD41 read failed: %s", esp_err_to_name(err));
        return false;
    }
    ESP_LOGI(TAG, "co2 %d ppm (sensor %.1fC %.0f%%)", r.co2_ppm, r.temp_c, r.humidity_pct);
    s_data.co2 = r;
    s_data.co2_ok = true;
    return true;
}

// Booted without WiFi (or NTP failed): sync once it's up. The RTC keeps the
// clock right meanwhile, if one is fitted.
static void tick_ntp(app_state_t *st)
{
    if (st->ntp_ok || ++st->seconds_since_ntp < NTP_RETRY_SECONDS || !wifi_is_connected()) return;
    st->seconds_since_ntp = 0;
    st->ntp_ok = (clock_sync_time() == ESP_OK);
    ESP_LOGI(TAG, "late NTP sync %s", st->ntp_ok ? "done" : "failed");
}

// Offline: hold the fetch until WiFi is back, then it fires right away.
static bool tick_weather(app_state_t *st)
{
    if (++st->seconds_since_weather < st->next_weather_interval || !wifi_is_connected()) return false;
    st->seconds_since_weather = 0;
    if (fetch_weather("refreshed")) {
        st->next_weather_interval = WEATHER_REFRESH_SECONDS;
        return true;
    }
    st->next_weather_interval *= 2;
    if (st->next_weather_interval > WEATHER_REFRESH_SECONDS)
        st->next_weather_interval = WEATHER_REFRESH_SECONDS;
    return false;
}

// Holidays change once a year: fetched at the first chance, again for the
// next year once this year's are all past; a failure retries in 30 min.
static bool tick_holidays(app_state_t *st)
{
    if (++st->seconds_since_holidays < HOLIDAYS_RETRY_SECONDS) return false;
    if (s_data.today_ymd == 0 || !wifi_is_connected()) return false;
    int year = holidays_wanted_year(&s_data.holidays, s_data.today_ymd);
    if (year == 0) return false;
    st->seconds_since_holidays = 0;
    holidays_t h;
    esp_err_t err = holidays_fetch(year, &h);
    if (err != ESP_OK) {
        ESP_LOGW(TAG, "holidays %d failed: %s", year, esp_err_to_name(err));
        return false;
    }
    int next = holidays_next(&h, s_data.today_ymd);
    ESP_LOGI(TAG, "holidays %d fetched (%d in Berlin, next %d %s)", year, h.count,
             next >= 0 ? h.day[next].ymd : 0, next >= 0 ? h.day[next].name : "-");
    s_data.holidays = h;
    return true;
}

// Heap and stack headroom, every few minutes and once a minute after boot
// (by then the first TLS fetch has run, so the numbers mean something).
static void tick_health(app_state_t *st)
{
    if (++st->seconds_since_health < HEALTH_LOG_SECONDS) return;
    st->seconds_since_health = 0;
    health_log();
}

// Readings to the dashboard (server/), handed to the upload task.
static void tick_metrics(app_state_t *st)
{
    if (++st->seconds_since_metrics < METRICS_SECONDS || !wifi_is_connected()) return;
    st->seconds_since_metrics = 0;
    metrics_device_t dev = {
        .uptime_s = (long)(xTaskGetTickCount() / configTICK_RATE_HZ), // wraps after ~497 days
        .heap_free_kb = (int)(esp_get_free_heap_size() / 1024),
    };
    dev.rssi_ok = wifi_rssi(&dev.rssi);
    char lines[512];
    if (metrics_format(&s_data, &dev, lines, sizeof(lines)) < 0) {
        ESP_LOGW(TAG, "metrics batch too big");
        return;
    }
    metrics_submit(lines);
}

// Waits out the rest of this second, reacting to the encoder (and web API
// commands, which come through its queue) straight away instead of on the
// next tick. A quick spin queues several clicks: they're all applied, then
// drawn once. Press turns the panel off/on; a turn while it is off only
// wakes it, without switching screens. A web screen pick also wakes it.
static void wait_second_handling_encoder(TickType_t *next_second)
{
    *next_second += pdMS_TO_TICKS(1000);
    if ((int32_t)(xTaskGetTickCount() - *next_second) > 0) {
        *next_second = xTaskGetTickCount(); // overran (slow fetch): don't try to catch up
    }
    for (;;) {
        TickType_t now = xTaskGetTickCount();
        if ((int32_t)(*next_second - now) <= 0) return;
        input_event_t ev;
        if (!encoder_wait_event(&ev, *next_second - now)) continue;
        int screen = s_screen;
        bool on = s_panel_on;
        do {
            if (ev.type == INPUT_PRESS) on = !on;
            else if (ev.type == INPUT_PANEL) on = ev.arg != 0;
            else if (ev.type == INPUT_SCREEN) {
                screen = ev.arg;
                on = true;
            } else if (!on) on = true; // a turn while off just wakes the panel
            else if (ev.type == INPUT_CW) screen = (screen + 1) % SCREEN_COUNT;
            else screen = (screen + SCREEN_COUNT - 1) % SCREEN_COUNT;
        } while (encoder_wait_event(&ev, 0));
        if (on != s_panel_on) {
            s_panel_on = on;
            ESP_LOGI(TAG, "panel %s", on ? "on" : "off");
            display_set_on(on);
        }
        if (screen != (int)s_screen) {
            s_screen = screen;
            ESP_LOGI(TAG, "screen %d", screen);
            draw_screen();
        }
        web_publish(&s_data, s_screen, s_panel_on);
    }
}

void app_main(void)
{
    // Indoor read on the first pass, health report 60s in.
    app_state_t st = {
        .seconds_since_indoor = INDOOR_REFRESH_SECONDS,
        .seconds_since_health = HEALTH_LOG_SECONDS - 60,
        .seconds_since_holidays = HOLIDAYS_RETRY_SECONDS,
        .last_minute = -1,
    };

    i2c_master_bus_handle_t bus = i2c_init();
    bool brownout = last_reset_was_brownout();
    i2c_bus_check(bus);

    ESP_ERROR_CHECK(display_init(bus));
    ESP_ERROR_CHECK(display_clear());
    ESP_LOGI(TAG, "OLED init OK");

    splash_begin(brownout);
    boot_local(bus, &st);
    boot_network(&st);
    // No hold: the fast cells are read while WiFi/NTP/weather are still
    // pending, so the main screens follow the last status straight away.
    start_background();

    ESP_ERROR_CHECK(display_clear());
    s_screen = SCREEN_HOME;
    draw_screen();
    // Before the first tick, whose fetches (holidays) can block for seconds:
    // the web server is already answering.
    web_publish(&s_data, s_screen, s_panel_on);

    TickType_t next_second = xTaskGetTickCount();
    for (;;) {
        draw_clock_row();
        bool changed = tick_minute(&st);
        changed |= tick_bvg();
        changed |= tick_indoor(&st);
        changed |= tick_co2(&st);
        tick_ntp(&st);
        changed |= tick_weather(&st);
        changed |= tick_holidays(&st);
        tick_health(&st);
        tick_metrics(&st);
        if (changed) draw_screen();
        web_publish(&s_data, s_screen, s_panel_on);
        wait_second_handling_encoder(&next_second);
    }
}

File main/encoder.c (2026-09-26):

#include "encoder.h"
#include "encoder_decode.h"
#include "driver/gpio.h"
#include "freertos/queue.h"
#include "freertos/task.h"
#include "esp_log.h"

static const char *TAG = "encoder";

#define ENC_CLK_GPIO    GPIO_NUM_25 // channel A
#define ENC_DT_GPIO     GPIO_NUM_26 // channel B
#define ENC_SW_GPIO     GPIO_NUM_27 // push button, active low
#define BTN_POLL_MS     10          // = 1 tick at CONFIG_FREERTOS_HZ=100
#define BTN_DEBOUNCE_MS 30

static QueueHandle_t s_events;
static enc_rotation_t s_rotation;

static uint8_t IRAM_ATTR pin_state(void)
{
    return (gpio_get_level(ENC_CLK_GPIO) << 1) | gpio_get_level(ENC_DT_GPIO);
}

// Rotation is decoded in the pin-change interrupt: polling at the 10ms tick
// would miss steps on a quick spin (bring-up saw ~30ms per detent).
static void IRAM_ATTR encoder_isr(void *arg)
{
    int click = enc_rotation_update(&s_rotation, pin_state());
    if (click == 0) return;
    input_event_t ev = {.type = (click > 0) ? INPUT_CW : INPUT_CCW};
    BaseType_t woken = pdFALSE;
    xQueueSendFromISR(s_events, &ev, &woken);
    portYIELD_FROM_ISR(woken);
}

static void button_task(void *arg)
{
    enc_button_t button;
    enc_button_init(&button);
    for (;;) {
        if (enc_button_update(&button, gpio_get_level(ENC_SW_GPIO), BTN_POLL_MS, BTN_DEBOUNCE_MS)) {
            input_event_t ev = {.type = INPUT_PRESS};
            xQueueSend(s_events, &ev, 0);
        }
        vTaskDelay(pdMS_TO_TICKS(BTN_POLL_MS));
    }
}

esp_err_t encoder_init(void)
{
    s_events = xQueueCreate(16, sizeof(input_event_t));
    if (!s_events) return ESP_ERR_NO_MEM;

    gpio_config_t io_conf = {
        .pin_bit_mask = (1ULL << ENC_CLK_GPIO) | (1ULL << ENC_DT_GPIO) | (1ULL << ENC_SW_GPIO),
        .mode = GPIO_MODE_INPUT,
        // The KY-040 has 10k pull-ups on CLK/DT, but SW's is often left
        // unpopulated -- the internal ones cover both cases.
        .pull_up_en = GPIO_PULLUP_ENABLE,
    };
    esp_err_t err = gpio_config(&io_conf);
    if (err != ESP_OK) return err;

    enc_rotation_init(&s_rotation, pin_state());
    gpio_set_intr_type(ENC_CLK_GPIO, GPIO_INTR_ANYEDGE);
    gpio_set_intr_type(ENC_DT_GPIO, GPIO_INTR_ANYEDGE);
    err = gpio_install_isr_service(0);
    if (err != ESP_OK && err != ESP_ERR_INVALID_STATE) return err; // INVALID_STATE = already installed
    gpio_isr_handler_add(ENC_CLK_GPIO, encoder_isr, NULL);
    gpio_isr_handler_add(ENC_DT_GPIO, encoder_isr, NULL);

    xTaskCreate(button_task, "enc_button", 2048, NULL, 5, NULL);
    ESP_LOGI(TAG, "ready (CLK=%d DT=%d SW=%d)", ENC_CLK_GPIO, ENC_DT_GPIO, ENC_SW_GPIO);
    return ESP_OK;
}

bool encoder_wait_event(input_event_t *ev, TickType_t timeout)
{
    if (!s_events) {
        vTaskDelay(timeout);
        return false;
    }
    return xQueueReceive(s_events, ev, timeout) == pdTRUE;
}

bool encoder_post(input_event_t ev)
{
    return s_events && xQueueSend(s_events, &ev, 0) == pdTRUE;
}

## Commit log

2026-09-16 Scope out desk info display project, record AliExpress hardware order
    CLAUDE.md covers concept, wiring plan, ESP-IDF components needed, and
    open questions. Parts ordered 2026-09-16: OLED, BME280, DS3231, rotary
    encoder, bulk ESP32-WROOM-32D boards, plus reserve WROVER-B for a
    future color-TFT project.
2026-09-20 Add ESP32 firmware: WiFi, NTP clock, OLED display, Open-Meteo weather
    Implements milestones 1-4: I2C SSD1306 bring-up, WiFi station, NTP time
    sync, and HTTPS weather fetch with icon rendering on the OLED. Milestone 5
    polish (icons, 15-min refresh cadence) also in place.
2026-09-20 Milestone 5 polish: network robustness, icon+temp on one row
    - NTP sync now retries with backoff instead of ESP_ERROR_CHECK aborting the
    device on a transient failure right after WiFi comes up.
    - Weather fetch backs off from 30s toward the normal 15-min cadence on
    failure, instead of leaving a stale reading up for the full interval.
    - display_draw_icon_and_text() draws the weather icon directly beside the
    temperature on one row instead of stacking them on separate pages.
    [display.c, main.c]
2026-09-23 Wire in DS3231 RTC, add boot status screen, fix NTP retry
    - clock: read the DS3231 (UTC) at boot to set system time before WiFi/NTP;
    write the NTP-synced time back after each successful sync. Skipped
    cleanly if the module is absent or its oscillator-stop flag is set.
    - clock: deinit SNTP after a failed sync wait. esp_netif_sntp_init()
    refuses a second init, so the backoff retries never actually retried.
    - display: full A-Z (classic glcdfont 5x7) replacing the HELLO-only letters.
    - main: boot status screen (OLED/RTC/WIFI/NTP/WEATHER going -- to OK/NO),
    shown immediately at power-on and held 7s after the last step.
    - CLAUDE.md: as-built wiring, RTC behaviour, OLED stale-frame gotcha,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
    [clock.c, display.c, main.c]
2026-09-23 Shorten boot status screen hold from 7s to 3s
    [main.c]
2026-09-23 Add README and Apache 2.0 license, tidy boot log messages
    - README: features, wiring, build/flash, configuration, layout, limitations
    - LICENSE: Apache License 2.0
    - main.c: drop dev-diary "milestone N" wording from log lines
    - CLAUDE.md: fix dangling reference to a nonexistent duty-tax note
    [main.c]
2026-09-23 Add power/bus guardrails: brownout PWR row, I2C address check, budget doc
    Boot shows PWR OK/NO from the reset reason (brownout = supply sagged) and
    scans the I2C bus against a KNOWN_I2C list, warning on unknown addresses.
    CLAUDE.md gains a power & bus budget table with rules for adding modules.
    [main.c]
2026-09-23 Read BME280 indoor data, two-column boot grid, clock+date on one row
    Hand-rolled BME280 driver (chip ID check, calibration, datasheet
    compensation, forced mode) shows indoor temp/humidity on the main screen.
    Boot status becomes a two-column grid with a BME cell; the main screen
    puts time and date on the top row, freeing space for more sensor data.
2026-09-23 Automatic DST via POSIX TZ rule, add ROADMAP checklist
    Replace the hand-flipped UTC_OFFSET_HOURS with the Berlin rule
    CET-1CEST,M3.5.0,M10.5.0/3. Since mktime() is now local time, RTC reads
    convert with a TZ-independent utc_to_epoch() helper. ROADMAP.md tracks
    the next tasks, one per session.
    [clock.c]
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2026-09-25 clang-tidy: .clang-tidy config, tools/lint.sh, codebase clean
    bugprone, clang-analyzer, misc and performance checks, findings fail the
    run. Fixed: explicit int->time_t / int->float conversions, missing default
    in the umlaut switch, one multi-declaration. NOLINT with reasons for an
    analyzer false positive (cJSON NULL checks) and, until they're split, the
    complexity of app_main() and draw_screen(). Lint configures its own
    build/clang tree with a private sdkconfig copy, so the gcc firmware build
    isn't forced into a full rebuild.
    [bme280.c, clock.c, encoder.c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]
2026-09-25 Flash budget check in CI, RAM health logging, real BVG fixture
    tools/size_check.sh fails below 15% free in the app partition. health.c
    logs heap (now/min/largest block) and per-task stack headroom 60s after
    boot and every 5 min, warning under 40 KB heap / 1 KB stack. bvg_real.json
    is a real departures response, caught while the wrapper was up.
    [main.c]
2026-09-25 Host tests for time math, encoder decode and font; glyphs checked as ASCII art
    Pure logic split out of the hardware files: clock_time.c (utc_to_epoch
    vs timegm 2000-2100, BCD, Berlin DST switch), encoder_decode.c (quadrature
    decode + button debounce), font.c (glyph tables + font_blit, which all
    display_draw_* text functions now share; fixes an out-of-bounds write on
    too-wide centered text). 47 tests. Roadmap: 4c done, auto-return/position
    indicator dropped.
    [clock.c, display.c, encoder.c]
2026-09-25 Lower OLED contrast to 0x40; drop the buzzer from the roadmap
    [display.c]
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2026-09-25 Dashboard: tooltips on what the numbers mean, colour ranges, 3h pressure change, uptime; generated by make_dashboard.py
2026-09-25 Berlin public holidays on HOME via Nager.Date (ROADMAP 10)
    NEXT HOLIDAY + date under the clock, or the name on the day; a DWD
    warning takes the row. http_get() moved to its own http.c. Nager.Date's
    cross-signed TLS chain needs CERTIFICATE_BUNDLE_CROSS_SIGNED_VERIFY.
2026-09-26 Phone page and JSON API at http://desk.local (ROADMAP 11)
    esp_http_server + mDNS: GET /api/status returns the screen data as JSON,
    POST /api/screen and /api/panel switch screens / panel like the knob,
    sent to the main loop through the encoder queue (now input_event_t).
    A small page at / for any phone browser. JSON building and command
    parsing are pure (web_api.c) and host-tested. Reading the API keeps BVG
    fetching for 2 min. +74 KB flash (30% free), heap lowest 116 KB.
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2026-09-26 docs/API.md: client contract for the phone app, kept in sync by a host test
    Discovery (NSD _http._tcp "Desk display", desk.local), every status
    field with units and null semantics, commands, errors, timing and polling
    guidance. docs/api/status.example.json is checked against the firmware's
    output by test_matches_documented_example.
    Also: publish the data to the web server before the first main-loop tick;
    until then /api/status said panel_on false and no data for the first
    seconds after boot, while the holidays fetch blocked the loop.
    [main.c]
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2026-09-26 SCD41 CO2 on the INDOOR screen (ROADMAP 13)
    Low-power periodic mode (30 s), polled from the main loop; CRC and
    conversion in the host-tested scd41_parse.c. Boot cell CO2 OK/NO.
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2026-09-26 SCD41: log the self-calibration (ASC) settings at boot (ROADMAP 14, step 1)
    Read while the sensor is idle, between stop and start. Commands and
    defaults checked against the SCD4x datasheet v1.7; the one-word parser
    is host-tested with its examples. Device reports: ASC enabled 1, target
    400 ppm, initial period 44 h, standard period 156 h.
2026-09-26 ROADMAP 14 done: keep SCD41 self-calibration on
    Display runs overnight (>= 4 h stretches, which ASC needs) and the room
    is aired at the desk, so ASC's fresh-air assumption holds. Fallback (ASC
    off + FRC) documented in CLAUDE.md.
2026-09-26 ROADMAP: task 15, enclosure + soldered carrier board; docs: build is on a breadboard now
2026-09-27 Dashboard: words on the tiles, online status, sections, restart markers
    - Tiles show a word above the number (Stuffy, Comfortable, Steady...),
    from the same bounds as the colours; Outdoor shows the weather code as
    text. Numbers stay the main value.
    - Uptime tile replaced by Display: Online / Offline for <duration>;
    uptime moved to the Device section, as a duration.
    - Legends show min/max/mean; wind/UV and WiFi/heap get separate axes;
    pollen gets low/medium/high bands and hides types at zero.
    - Room / Outside / Device rows (Device collapsed), restart markers from
    uptime drops, Europe/Berlin time zone.
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2026-09-28 Enclosure: knob board hole size corrected to 2.85
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2026-09-28 Enclosure: OpenSCAD model, export script with clash check, renders
    Shell (tilted OLED panel, knob on top), base with carrier standoffs and
    sensor pockets, sensor-bay hood, OLED clamp bars, and a test_front piece
    for the first test print. KY-040 shaft position still assumed.
    [enclosure.scad]
2026-09-28 Enclosure: KY-040 shaft position measured (~8.6 mm from the end without pins)
    [enclosure.scad]
2026-09-28 Enclosure: show_* toggles to hide printed parts in the assembly view
    [enclosure.scad]
2026-09-28 Enclosure: labels over the module stand-ins
    [enclosure.scad]
2026-09-28 Enclosure: cardboard mock-up templates (cardboard.py, 1:1 A4 PDF from the model)
    [enclosure.scad]
2026-09-28 CLAUDE.md: battery plan worked out (UPS module + flat LiPo), not ordered yet
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2026-09-28 Enclosure v2: carrier is the 4 x 6 cm board (ESP32 along its long side)
    The mock-up showed the ESP32 can't cross the board's 4 cm side (14 holes,
    15 pins). enclosure_v2.scad keeps v1 intact and offers carrier=cut (board
    cut to 40 x 44, USB out the back) and carrier=whole (uncut, USB out the
    right side); the DS3231 moves to its own floor holder with a cable.
    export.sh and cardboard.py now take a model file and variables.
    [enclosure_v2.scad]
2026-09-28 Enclosure v2: JST-XH sockets on the carrier's hole grid, with clash check
    whole fits all five sockets; cut only three (no room for BME280 and RTC).
    [enclosure_v2.scad]
2026-09-28 Session close: enclosure lessons in CLAUDE.md, ESP32 pin order in WIRING.md, roadmap next step
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2026-09-29 CLAUDE.md: Berrybase part options and reboot-free alternatives for the battery
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2026-10-02 Tools: serial_log.py takes PORT and survives an unplug; export.sh fails on model warnings, wipes stale STLs
    Both brought over from esp32-mukklet's copies of these scripts.
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2026-10-03 Enclosure: carrier layout 'whole' picked (USB out the right side), now the v2 default
    [enclosure_v2.scad]
2026-10-03 Enclosure v3: ESP32 mini instead of the DevKit, all five sockets in one stack
    [enclosure_v3.scad]
2026-10-17 BVG: switch to the official VBB API (ROADMAP 4b)
    The community wrapper v6.bvg.transport.rest had been returning 503 for
    months. bvg.c now queries VBB's HAFAS departureBoard (test system for now)
    with the access ID from bvg_secrets.h. The response is ~4 KB of JSON per
    departure, so bvg_parse.c hands one departure object at a time to cJSON,
    and the fetch buffer moved to the heap (32 KB, during the fetch only).
    Screen, task and API JSON are unchanged. Fixtures replaced with a real
    VBB capture plus a hand-written one for delay/cancelled/no-live/midnight.
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2026-10-18 Enclosure v4: the case to print (DevKit, no battery), v2 'whole' + mukklet's print lessons
    Front plate (OLED clamps reachable), strip under the screen on the base,
    base over the whole footprint with 4.0 holes, nut-mounted knob, pre-print
    asserts; export.sh fails on them, lists ASSUMED values, reads the part list
    from the model and clash-checks printed parts and stand-ins against each other.
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2026-10-25 Enclosure: reprint checklist, hole clearances E1-E4 recorded
    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
2026-10-25 Enclosure: 2 x 4 screw tried in the OLED's holes: fits, head ends at the flex
    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
2026-11-01 Panel off after 5 idle minutes; save readings while the server is down
    A power cut brought the display back but not the home server, and every
    reading until the server returned was lost.
    Failed uploads now go to a 2.5 MB flash partition (~44 days at 40 B a
    minute, oldest dropped when full) and are sent with their original times
    once the server answers. Every upload carries the device's time. Flash is
    only written while uploads fail.
    The panel goes off after 5 minutes without a knob or web command; polling
    /api/status doesn't count. BVG no longer fetches for a dark panel.
2026-11-01 Docs: panel isn't always lit now, backlog test recipe; serial_log on the mini's port
    serial_log.py defaulted to the old DevKit's /dev/ttyUSB0. Also commits the
    pending CLAUDE.md update: Homebox doesn't track what's free or in use.
2026-11-01 CI: pin the runner to ubuntu-24.04
    ubuntu-latest added a notice to every run about its move to Ubuntu 26. The
    job runs in the ESP-IDF container, so the host version doesn't matter.
